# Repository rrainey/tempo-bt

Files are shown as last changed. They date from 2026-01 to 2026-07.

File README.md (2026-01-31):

# Tempo-BT

Tempo-BT is the Bluetooth-LE-capable version of the Tempo skydiving logger device.  It is based on the u-blox NORA-B106 (Nordic Semiconductor nRF5340).

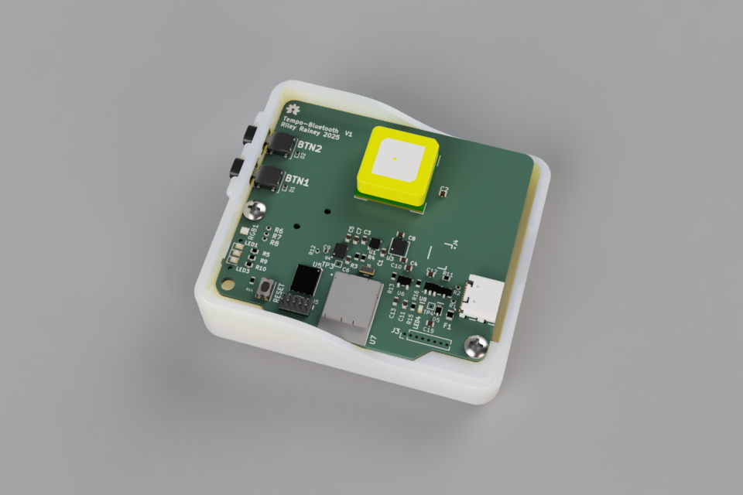
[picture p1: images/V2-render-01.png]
Tempo-BT


### Sensors and Capabilities

- GPS/GNSS position tracking using a u-blox SAM-M10Q
- 6-DOF Inertial measurement / gyro pose tracking using a TDK InvenSense ICM-42688-V
- Barometric pressure / temperature logging using a Bosch BPM390
- 3-DOF Compass/Magnetic measurement using a Memsic MMC5983MA (not utilized in the current version of the project)

## Directory Structure

| Folder | Description |
| --- | --- |
| hardware | KiCad PCB project (using KiCad 9) |
| enclosure | 3D-printable enclosure and assembly instructions (Fusion360 format) |
| zephyr/tempo-bt-v1 | Nordic nRF Connect SDK (Zephyr) firmware |

## LiPo Powered
The device is designed to use a 3.7V 850mAh rated USB-rechargeable battery.  Testing demonstrates the device and current firmware combination consumes 14.8 milliamps in idle mode and 17.4 milliamps in jump logging mode. Although I'd suggest power-cycling the device between jumps, this design should easily allow for two days of continuous use.

## Enclosure

The enclosure is designed to be SLA printable. 

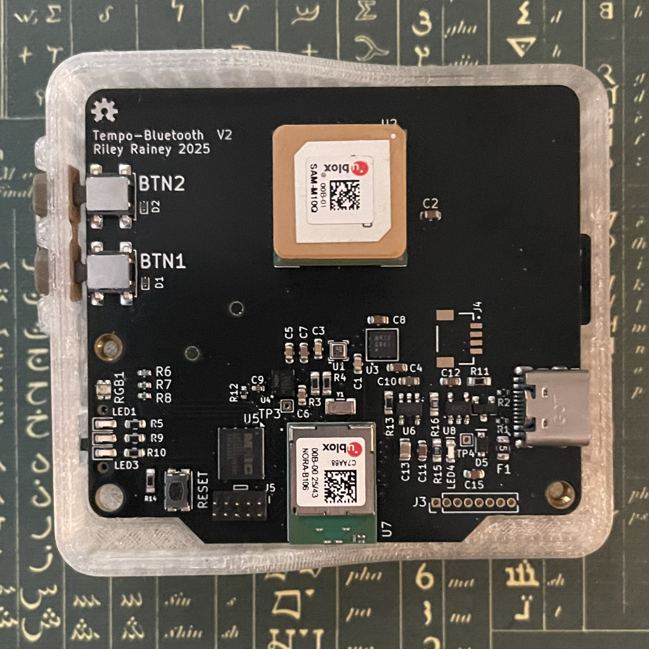
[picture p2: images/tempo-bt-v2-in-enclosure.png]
Enclosure


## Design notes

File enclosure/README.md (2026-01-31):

This snap-to-close enclosure was designed using Fusion 360 and optimized for printing using PLA filament on a Creality Ender V3 KE printer.

## Print Settings

I used the default settings in Creality Print for PLA-CR printing with a 0.4mm head and 0.2mm resolution. These settings were used for all three parts.

For other printers, here's what that amounts to:

| Parameter | Description |
|---|---|
| Filament Type | Standard PLA |
| Print Resolution | 0.2 mm |
| Brim | None |
| Supports | None - enable if Pushbutton insert doesn't fit well |
| Infill | Slicer Default (15%?) |

## Assembly

Two M2.5 brass inserts must be installed in the bottom half of the enclosure. M2.5 x 6 screws secure the PCB to the bottom enclosure.

| Quantity | Part Name | MFR Part Number | 
|---|---|---|
| 1 | Tempo BT V2 Board | NA |
| 1 | 3.7V 850mAh LiPo Battery | [13854](https://www.digikey.com/en/products/detail/sparkfun-electronics/13854/6605201) |
| 2 | Heat-Set Insert: M2.5-0.45 Thread Size | [1GNL7](https://www.grainger.com/product/Heat-Set-Insert-M2-5-0-45-1GNL7?searchQuery=1GNL7&searchBar=true) |
| 2 | Machine screw: M2.5x0.45 Thread Size, 5 mm | [1-mpp-2.5-5](https://www.grainger.com/product/Machine-Screw-M2-5x0-45-Thread-856Z30) |
| 1 | Enclosure Shell Bottom, PLA | Enclosure-Bottom.step |
| 1 | Enclosure Shell, Top, PLA | Enclosure-Top.step |
| 1 | Pushbutton Insert, PLA | Pushbutton.step |

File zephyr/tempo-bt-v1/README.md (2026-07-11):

# Tempo-BT - A Skydiving Data Logger

A Zephyr RTOS-based flight data logging system for the nRF5340 platform, designed for capturing high-frequency sensor data during skydiving and other aerial activities. The system logs IMU, barometric, GPS, and optional magnetometer data to SD card or internal flash storage, with Bluetooth LE connectivity for wireless data transfer and configuration.

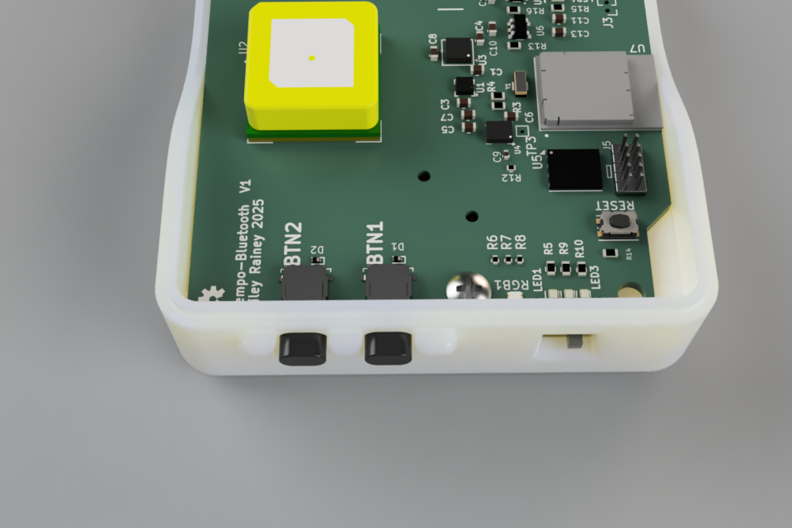
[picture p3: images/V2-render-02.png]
Tempo-BT-V2


## Table of Contents

- [Features](#features)
- [Hardware Requirements](#hardware-requirements)
- [Software Prerequisites](#software-prerequisites)
- [Build Instructions](#build-instructions)
- [Configuration](#configuration)
- [Usage Examples](#usage-examples)
- [Data Format](#data-format)
- [LED Status Indicators](#led-status-indicators)
- [Troubleshooting](#troubleshooting)
- [License](#license)
- [Support](#support)

## Features

- **Runs on the [Tempo-BT V1 Board](../../hardware/tempo-bt)**
  - open source hardware design
  - part of this GitHub repository
  - Design based on an FCC-certified u-blox NORA-B106 SOC

- **High-frequency sensor logging**
  - 50 Hz IMU data (TDK InvenSense ICM-42688-V)
  - 4 Hz barometric pressure/temperature (Bosch BMP390)
  - 2-10 Hz GPS (u-blox SAM-M10Q)
  - Optional magnetometer support (MMC5983MA) (not yet supported in firmware)

- **Flexible storage options**
  - Primary: SD card via SPI (includes exFAT support)
  - Fallback: Internal QSPI flash (littlefs)
  - Automatic storage detection at boot

- **Wireless connectivity**
  - Bluetooth LE with mcumgr protocol
  - File transfer over BLE (100-200 KB/s) (estimated)
  - Remote configuration and control
  - OTA firmware updates over BLE/SMP (MCUboot; validated 1.4.0 → 1.5.0 — see [DFU/OTA test plan](docs/dfu-ota-test-plan.md))

- **Intelligent logging**
  - Automatic logging based on environmental conditions - the device starts logging when the jumppland leaves the ground and closes the log after landing
  - State machine with flight phase detection

## Hardware Requirements

- **Development Board**: nRF5340 DK or custom Tempo-BT V2 board
- **Sensors** (connected as per hardware documentation):
  - ICM-42688-V IMU (SPI)
  - BMP390 Barometer (I²C)
  - SAM-M10Q GNSS module (115200 bps UART)
  - Optional: MMC5983MA Magnetometer (I²C)
- **Storage**: SD card (recommended) or internal 8MB QSPI flash

## Software Prerequisites

### Development Environment

1. **Visual Studio Code**
   - Download and install from [https://code.visualstudio.com/](https://code.visualstudio.com/)

2. **nRF Connect SDK v3.1.0**
   - Install the nRF Connect for VS Code extension
   - Use the extension to install nRF Connect SDK v3.1.0
   - Ensure toolchain v3.1.0 or later is selected

3. **Additional Tools**
   - Python 3.8 or higher
   - Git
   - Python `smpmgr` tool  ([link](https://pypi.org/project/smpmgr/)) (see below)

### VS Code Configuration

Configure your build in VS Code using these settings:

VS Code Build Configuration

Key configuration points:
- **SDK**: nRF Connect SDK v3.1.0
- **Toolchain**: nRF Connect SDK Toolchain v3.1.0
- **Board target**: nrf5340dk/nrf5340/cpuapp
- **Base configuration**: prj.conf
- **Device tree overlay**: boards/tempo_v1.overlay

## Build Instructions

### 1. Clone the Repository

```bash
git clone https://github.com/rrainey/tempo-bt
```

### 2. Open in VS Code

```bash
code .
```

### 3. Build the Project

Using VS Code:
1. Open the nRF Connect extension sidebar
2. Click "Add Build Configuration"
3. Select the settings as shown in the configuration image above
4. Click "Generate and Build"

Using Command Line:
```bash
west build -b nrf5340dk_nrf5340_cpuapp -p auto
```

### 4. Flash the Firmware

Using VS Code:
- Click the "Flash" button in the nRF Connect extension

Using Command Line:
```bash
west flash
```
## Interacting with the device

The device is intended for use with the [tempo-insights](https://github.com/rrainey/tempo-testbed) application suite.  It leverages the Bluetooth hardware to communicate with a Tempo-BT device.

That application repository includes extensions to the Python-based `smpmgr` command line tool ([link](https://pypi.org/project/smpmgr/)).  You can see examples of and experiment with interacting with a Tempo-BT device using that tool.

#### Notes on UUIDs

- Both `user_uuid` and `device_uuid` are automatically generated on first boot
- UUIDs are version 4 (random) format
- The `user_uuid` is intended to identify the person using the device (although we don't use that today)
- The `device_uuid` uniquely identifies this specific hardware unit
- UUIDs are displayed in standard format (e.g., `550e8400-e29b-41d4-a716-446655440000`)
- When setting UUIDs via mcumgr, provide them as 32 hex characters without dashes

#### Persistence

All settings are stored in non-volatile memory and persist across power cycles and firmware updates.

This revised section provides comprehensive documentation for all available settings, including examples of how to read and write each one using mcumgr commands.

### Manual Control

The device can also be controlled via the onboard BTN1 button (nearest the USB port):
- **BTN1 Long press (2s)**: Manually start logging

## Data Format

Jump logs are stored in a date-organized tree in `/logs/` on the device SD card.  The log file format is described in [LOG-FORMAT.md](docs/LOG-FORMAT.md)

## LED Status Indicators

A GREEN LED is used as a power indication.

The RGB LED provides visual system status:

| Color | Pattern | State |
|---|---|---|
| Off | N/A | ARMED - Ready (green / red side LEDs indicate GNSS Fix State) |
| Green | Slow pulse | Logging - waiting for aircraft exit |
| Orange | Slow pulse | Logging - in freefall or under canopy |
| White | Solid | File transfer active (not yet implemented) |
| Red | Slow pulse | Fatal Error |
| Blue | Slow Pulse | IDLE - not used in the current implementation |

Additionally, there is a dedicated RED LED which will blink when there is no usable GPS signal; the GREEN LED nearest the user buttons will flash once per second when the GNSS receiver has a valid 3D Fix.

A separate AMBER LED is the USB charging indicator.

## Firmware Update over BLE (OTA DFU)

The device supports over-the-air firmware upgrades over Bluetooth using MCUboot and the
mcumgr/SMP protocol. There is **no serial/USB DFU** — updates arrive over the same BLE link
used for file transfer. This procedure is validated (see
[DFU/OTA test plan](docs/dfu-ota-test-plan.md)); the steps below are the reusable recipe.

### How it works

The nRF5340 is dual-core, so a full update ships **two images** — the application core and
the network (radio) core — packaged together in `build/dfu_application.zip`
(`tempo-bt-v1.signed.bin` = app, `ipc_radio.bin` = net core, plus a manifest). Both images
are uploaded to staging slots in the **external QSPI flash**, marked pending, and applied on
a single reboot: MCUboot overwrites the application slot and uses the PCD library to
reprogram the network core. Images are signed and validated by MCUboot before they are
accepted.

> ⚠️ **The build is overwrite-only: there is no automatic rollback.** A bad image — most
> dangerously a bad network-core image that breaks BLE — cannot self-recover. Recovery is a
> wired SWD/J-Link re-flash of `build/merged.hex` + `build/merged_CPUNET.hex` (see
> [Flash the Firmware](#4-flash-the-firmware)). For first-time or risky updates, use a
> device you can reach with a debugger.
>
> Production flight logs are **not** touched: the DFU staging slots live in a separate region
> of the external flash from the LittleFS log partition.

### Prerequisites

- `smpmgr` on PATH (`pip install smpmgr`). The DFU path uses only smpmgr's **native**
  `image`/`os`/`file` groups — the Tempo group-64 plugin is **not** required.
- A current DFU package at `build/dfu_application.zip` (produced by the normal sysbuild build).
- The target device powered on and advertising within BLE range.

### Scripted upgrade (recommended)

[`tools/dfu-upgrade.sh`](tools/dfu-upgrade.sh) performs the whole flow for one device and
verifies it — resolve by name, stage both images, mark both pending, reset (retrying until
the swap actually applies), re-discover by name, and confirm the running image. It is
version-agnostic (the upgrade target is whatever the package stages) and touches no flight
logs.

```bash
# uses build/dfu_application.zip by default; pass a path to use a different package
tools/dfu-upgrade.sh 0006
tools/dfu-upgrade.sh 0006 /path/to/dfu_application.zip
```

It prints `RESULT Tempo-BT-0006: PASS …` and exits 0 on success. A non-zero exit before the
reset leaves the device untouched (still on the old image); a non-zero exit after means the
swap did not take — recover/inspect via SWD. Requires `smpmgr`, `bluetoothctl`, `python3`,
`unzip`; the companion state parser is [`tools/dfu_state_parse.py`](tools/dfu_state_parse.py).
The manual steps below are exactly what the script automates.

### Procedure (manual)

```bash
# 0. Extract the two images from the DFU package
cd build
unzip -o dfu_application.zip     # → tempo-bt-v1.signed.bin, ipc_radio.bin, manifest.json

# 1. Find the device address. The BLE MAC is randomly assigned at each power-on, so always
#    resolve it by advertised name (Tempo-BT-nnnn) rather than a remembered address:
bluetoothctl --timeout 8 scan on | grep "Tempo-BT-0001"     # note the AA:BB:.. address
DEV=<address-from-scan>

# 2. Baseline — confirm SMP is up and record the running image hash:
smpmgr --ble $DEV os echo hello
smpmgr --ble $DEV image state-read      # note slot0/image0 hash = the OLD firmware

# 3. Stage both images (non-destructive — the device keeps running the old firmware).
#    NOTE: smpmgr's "--slot" is really the nRF5340 IMAGE NUMBER: 0 = app core, 1 = net core.
smpmgr --timeout 30 --ble $DEV image upload tempo-bt-v1.signed.bin --slot 0
smpmgr --timeout 30 --ble $DEV image upload ipc_radio.bin          --slot 1

# 4. Confirm both are staged, and copy the two staged hashes for the next step:
smpmgr --ble $DEV image state-read
#   expect: image0/slot1 = new app hash, image1/slot1 = new net hash (both pending=False here)

# 5. Mark both staged images pending (confirm=false). THIS IS THE POINT OF NO RETURN:
smpmgr --ble $DEV image state-write <NEW_APP_HASH> false
smpmgr --ble $DEV image state-write <NEW_NET_HASH> false
smpmgr --ble $DEV image state-read      # verify both staged images now show pending=True

# 6. Apply. The device reboots, overwrites the app slot, and reprograms the net core.
#    This swap takes ~30-45 s (much longer than a plain reboot). `os reset` can silently
#    fail to trigger — if step 7 still shows the OLD hash with the images still pending,
#    the device never rebooted; re-issue os reset.
smpmgr --ble $DEV os reset

# 7. Rediscover by name (the reboot is a new power-on → the MAC may change), then verify:
bluetoothctl --timeout 8 scan on | grep "Tempo-BT-0001"     # ← must still advertise its name
DEV=<new-address-from-scan>
smpmgr --ble $DEV os echo hello                              # BLE/net core OK
smpmgr --ble $DEV image state-read                          # running slot0 hash == NEW_APP_HASH,
                                                            #   active=True, confirmed=True,
                                                            #   and the pending images are gone
```

### Acceptance checks

- `image state-read` shows the running application image hash equal to the newly-uploaded
  app image, `active` and `confirmed`. (The MCUboot image *version* field reads `0.0.0` and
  is **not** a usable version signal — verify by hash.)
- The device still advertises its assigned `Tempo-BT-nnnn` name and answers `os echo` —
  this confirms the network core survived the update.
- `smpmgr --ble $DEV file read-size <path>` responds — file transfer intact.

### Notes

- **Single-image shortcut:** for an app-core-only update you can use smpmgr's one-shot
  `smpmgr --ble $DEV upgrade <image>` (upload + mark pending + reset). The dual-core case
  above deliberately stages both images before the single reset.
- **Typical timing** (single scan adapter): app-core upload (~337 KB) ≈ 23 s, net-core
  upload (~172 KB) ≈ 13 s, and the reboot+swap (both cores) ≈ 30–45 s before the device is
  reachable again → roughly 75–90 s end to end. (A ~11 s "reboot" means the swap did **not**
  happen — the reset didn't take; re-issue it.)
- **BLE reliability:** intermittent "device not found" / dropped requests are almost always
  **BT adapter contention**, not the device — running multiple controllers at once (e.g. the
  transfer-dongle pool alongside the onboard radio) makes BlueZ/bleak discovery flaky. Do
  DFU with a single active controller if you hit this. Direct `smpmgr` connects to a known
  address are far more reliable than `bluetoothctl scan`; since a device keeps its BLE MAC
  across a reboot, verify a post-reset swap by polling its address, not by re-scanning.

## Planned firmware work

Driven by the `tempo-tb-ingest` automated-harvest workstream:

- **`SESSION_LIST` pagination** — extend the custom group-64 `SESSION_LIST` command to
  return sessions in pages, so devices holding large numbers of sessions can be
  enumerated reliably over BLE without exceeding SMP payload limits.
- **Firmware version in `settings-get`** — add a firmware-version field to the
  `settings-get` response (to be implemented alongside the pagination change). This gives
  clients a first-class version indicator; today the only over-BLE version signal is the
  MCUboot image hash (the MCUboot image *version* is `0.0.0`, so it is not usable), which
  is why the [DFU/OTA test plan](docs/dfu-ota-test-plan.md) verifies upgrades by image-hash
  match rather than a version string.

## Troubleshooting

### Common Issues

1. **SD card not detected**
   - Verify card is properly inserted
   - Validate that the SD card is readable on a PC
   - Check for supported card size (max 32GB recommended)

### Debug Output

Connect via RTT to see debug messages:
```bash
JLinkRTTViewer
```

## Acknowledgments

This project incorporates the following open-source libraries:

### Fusion AHRS Algorithm

The orientation tracking system uses the **Fusion** sensor fusion library by [xioTechnologies](https://x-io.co.uk/):

- **Project**: Fusion - Sensor Fusion Library for Inertial Measurement Units (IMUs)
- **Author**: Seb Madgwick
- **Repository**: https://github.com/xioTechnologies/Fusion
- **License**: MIT License
- **Usage**: Provides AHRS (Attitude and Heading Reference System) quaternion estimation from gyroscope and accelerometer data

The Fusion library implements a complementary filter with adaptive gain, gyroscope bias correction, and rejection of acceleration disturbances. It is specifically optimized for embedded systems.

**Citation**:
```
Madgwick, S. (2021). Fusion - Sensor Fusion Library for IMUs [Software].
Available from https://github.com/xioTechnologies/Fusion
```

## License

This project is licensed under the Apache License 2.0. See the [LICENSE](LICENSE) file for details.

```
Copyright 2025 Tempo-BT Contributors

Licensed under the Apache License, Version 2.0 (the "License");
you may not use this file except in compliance with the License.
You may obtain a copy of the License at

    http://www.apache.org/licenses/LICENSE-2.0

Unless required by applicable law or agreed to in writing, software
distributed under the License is distributed on an "AS IS" BASIS,
WITHOUT WARRANTIES OR CONDITIONS OF ANY KIND, either express or implied.
See the License for the specific language governing permissions and
limitations under the License.
```

## Support

For questions, bug reports, or feature requests:

- **Primary Contact**: Riley Rainey ([@rileyrainey](https://x.com/rileyrainey) on X.com)
- **Issues**: Please file issues on the project's GitHub repository
- **Documentation**: Additional documentation can be found in the `docs/` directory

### Contributing

Contributions are welcome!

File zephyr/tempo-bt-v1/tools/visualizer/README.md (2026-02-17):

# Tempo-BT Orientation Visualizer

This Python desktop application connects to a Tempo-BT device over USB and renders its real-time orientation in 3D. It parses the `$PIM2` (quaternion) and `$PIMU` (accelerometer/gyroscope) NMEA sentences from the Tempo-BT USB TTY log stream.

The application demonstrates the Tempo device's ability to compute a skydiver's orientation in real time using the on-board ICM-42688 IMU and Fusion AHRS algorithm. A telemetry overlay displays live accelerometer and gyroscope readings alongside the 3D view.

## Prerequisites

- Tempo-BT device with firmware v1.1.0 or later (USB CDC-ACM support)
- USB cable connecting Tempo-BT to your desktop machine
- Python 3.9+

## Setup

1. Open a terminal in the `tools/visualizer` folder.

2. Set up a Python virtual environment (recommended):

```
$ python -m venv .venv
$ .venv\Scripts\activate
```

or Powershell:

```
> .venv\\Scripts\\Activate.ps1 
```

On Windows, you may need to allow script execution first:
```
> Set-ExecutionPolicy -ExecutionPolicy RemoteSigned -Scope CurrentUser
```

3. Install dependencies:

```
> pip install -r requirements.txt
> pip install PyOpenGL PyOpenGL_accelerate
```

*Installation of `PyOpenGL_accelerate` is optional.* It may require Microsoft Visual Studio or a prebuilt wheel. See [this guide](https://stackoverflow.com/questions/77346740/install-pyopengl-for-windows-under-python-3-12) for prebuilt options.

## Running

1. Connect Tempo-BT to your desktop via USB.

2. Start the visualizer:

```
> python visualizer.py
```

The application auto-detects the Tempo-BT device by its USB VID (`0x1209`) and PID (`0x2026`). If auto-detection fails (e.g., multiple devices or driver issues), specify the port manually:

```
> python visualizer.py --port COM8
```

3. On the Tempo-BT device, long-press **BTN2** (2 seconds) to start the USB log stream.

4. The 3D model will rotate to mirror the device's physical orientation. The top-right overlay shows live IMU telemetry (accelerometer in m/s², gyroscope in rad/s).

5. Long-press **BTN2** again to stop streaming, or simply disconnect the USB cable.

## Keyboard Controls

| Key | Action |
|-----|---|
| **F** | Front view |
| **R** | Right view |
| **Q** | Quit |

## NMEA Sentences

The visualizer processes these sentences from the USB stream:

| Sentence | Rate | Usage |
|---|---|---|
| `$PIM2` | 20 Hz | Quaternion orientation (w, x, y, z) for 3D rendering |
| `$PIMU` | 20 Hz | Accelerometer + gyroscope values for telemetry overlay |

All other sentences (`$PENV`, `$PST`, `$PVER`, `$GxGGA`, `$GxVTG`, `$GxRMC`, etc.) are silently ignored.

## Troubleshooting

- **"No Tempo-BT device found"**: Ensure the device is connected via USB and appears as a COM port in Device Manager. Use `--port COMx` if auto-detection fails.
- **No data streaming**: Make sure you long-pressed Button 1 / BTN2 on the Tempo-BT to start the USB log stream. The green LED indicates the device is in LOGGING state.
- **3D model orientation seems wrong**: Set the device flat on your desk with the USB connector coming out the left side, then press F for front view to establish a reference.

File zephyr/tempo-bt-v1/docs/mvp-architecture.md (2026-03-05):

# Tempo-BT (V1) — Zephyr Device Application Architecture

> Scope: architecture for the **V1 prototype** (nRF5340 / NORA-B106) with ICM-42688-V (SPI), BMP390 (I²C), optional MMC5983MA (I²C), u-blox SAM-M10Q (UART), **SD Card** (FAT/exFAT).
> Focus areas per request:
>
> 1. **File + folder (project) structure**
> 2. **What each part does**
> 3. **Where state lives & how services connect**

---

## 1) Project Layout (top-level folders and key files)

```
tempo-bt/
├─ CMakeLists.txt                # Zephyr app build entry
├─ prj.conf                      # Kconfig: features, stacks, logging, BLE, FS
├─ Kconfig                       # App-specific config symbols (USB_TTY_OUTPUT, etc.)
├─ west.yml                      # (optional) NCS/Zephyr manifest pinning
│
├─ boards/
│  └─ nrf5340dk_nrf5340/
│     ├─ tempo_v1.overlay        # DeviceTree overlay: pins/buses/IRQs/USB for V1
│     └─ tempo_v1.conf           # Board-specific prj.conf deltas (if needed)
│
├─ include/
│  ├─ app/events.h               # Event IDs, payloads, and helper macros
│  ├─ app/log_format.h           # $Pxxx sentence format & helpers (NMEA)
│  │
│  ├─ services/timebase.h        # Time service API (monotonic, GNSS tie)
│  ├─ services/imu.h             # ICM42688 sample structs & API
│  ├─ services/baro.h            # BMP390 sample structs & API
│  ├─ services/gnss.h            # GNSS NMEA/UBX ingest API
│  ├─ services/aggregator.h      # Merges streams → record/sentence builder
│  ├─ services/logger.h          # Logging session lifecycle & policies
│  ├─ services/file_writer.h     # Async buffered writer (ring buffer)
│  ├─ services/storage.h         # Storage abstraction (littlefs/FATFS)
│  ├─ services/orientation.h     # AHRS/orientation tracking API
│  ├─ services/led.h             # RGB LED service API
│  ├─ services/usb_tty.h         # USB CDC-ACM TTY output API (ground test)
│  │
│  └─ fusion.h                   # Fusion AHRS algorithm headers
│
├─ src/
│  ├─ main.c                     # Init order, button handling, event loop
│  ├─ app_init.c                 # Storage mount, BLE/mcumgr initialization
│  ├─ events.c                   # Event bus (k_fifo/k_msgq) + subscribers
│  ├─ fusion.c                   # Fusion AHRS algorithm (xioTechnologies)
│  │
│  ├─ services/
│  │  ├─ timebase.c             # 64-bit mono clock; GNSS time correlation
│  │  ├─ imu_icm42688.c         # SPI4 + INT1/FIFO DMA; ODR control
│  │  ├─ baro_bmp390.c          # I²C + DRDY; pressure/temperature
│  │  ├─ gnss_m10q.c            # UART async; NMEA/UBX parse; early quiet
│  │  ├─ aggregator.c           # Streams → `$PIMU/$PIM2/$PENV/...` w/ checksums
│  │  ├─ orientation.c          # AHRS wrapper using Fusion algorithm
│  │  ├─ logger.c               # Session mgmt; start/stop; takeoff detection
│  │  ├─ file_writer.c          # Ring buffer + worker thread
│  │  ├─ storage.c              # Storage abstraction layer
│  │  ├─ storage_littlefs.c     # QSPI NOR backend (optional)
│  │  ├─ storage_fatfs.c        # SD Card FAT/exFAT backend (primary)
│  │  ├─ usb_tty.c              # USB CDC-ACM TTY output (conditional)
│  │  └─ led.c                  # PWM-based RGB LED control
│  │
│  └─ util/
│     └─ nmea_checksum.c        # NMEA checksum utilities
│
├─ config/
│  └─ settings.c                 # Zephyr settings keys & defaults (`app/*`)
│
├─ docs/
│  └─ mvp-architecture.md        # This document
│
├─ tools/
│  └─ patch_rmc.py               # Retroactively insert RMC into old log files
│
└─ scripts/
   └─ host_tools/verify_log.py   # PC-side log validator
```

---

## 2) Runtime Architecture (what each part does)

### 2.1 Layered view

**Current implementation status:**
- ✓ BMP390 barometer (working, 8Hz with takeoff detection)
- ✓ GNSS SAM-M10Q (working, 1-10Hz dynamic, UBX config, RMC passthrough)
- ✓ SD Card storage (FAT/exFAT, primary storage)
- ✓ Orientation tracking (Fusion AHRS algorithm)
- ✓ RGB LED status (PWM-based, state indication)
- ✓ Button controls (short/long press handling)
- ✓ BLE file transfer (mcumgr)
- ✓ ICM42688 IMU (200Hz FIFO, filtered accel magnitude for freefall detection)
- ✓ Flight phase detection (takeoff, freefall, landing)
- ✓ USB CDC-ACM TTY output (ground testing via Button 1 / BTN2)
- ✓ MMC5983MA magnetometer (calibration via USB, AHRS integration, NVM persistence)

```mermaid
flowchart TB
  subgraph App["Application Layer"]
    Main[main.c\nButton handlers\nExecutive loop 250ms]
    Logger[Logger Service\nState machine\nFlight phase detection]
    LED[LED Service\nPWM RGB status]
  end

  subgraph Services["Core Services"]
    Agg[Aggregator\nSentence builder\nRing buffers]
    Orient[Orientation\nFusion AHRS]
    Writer[File Writer\nRing buffer + thread]
    UsbTty[USB TTY\nCDC-ACM output\nGround test mode]
    Tm[Timebase\n64-bit mono + RTC]
  end

  subgraph Drivers["Sensor + IO Drivers"]
    IMU[ICM42688 SPI\n200Hz FIFO\nFiltered accel mag]
    BARO[BMP390 I²C\nAlpha-beta filter]
    GNSS[SAM-M10Q UART\n1-10Hz dynamic]
    Storage[SD Card FAT]
  end

  Main --> Logger
  Main --> LED
  Logger --> Agg
  IMU --> Orient
  IMU --> Logger
  BARO --> Agg
  BARO --> Logger
  GNSS --> Agg
  Tm --> Agg
  Orient --> Agg

  Agg --> Writer --> Storage
  Agg -.-> UsbTty -.-> USB[USB Host]
```

### 2.2 Concurrency model (threads & priorities)

| Thread | Priority | Purpose |
|---|---|---|
| **File writer** | `K_PRIO_PREEMPT(10)` | Drains ring buffer to SD card |
| **Aggregator** | `K_PRIO_PREEMPT(5)` | Builds NMEA sentences |
| **GNSS RX** | `K_PRIO_PREEMPT(5)` | UART async callback context |
| **Main** | Default | Button handling, health monitoring |

**Communication primitives:**

* **Ring buffer** (Zephyr `sys/ring_buffer.h`) in file_writer for async I/O
* **Ring buffer** in USB TTY for interrupt-driven CDC-ACM TX (4KB)
* **Spinlock-protected ring buffers** in aggregator for IMU/BARO/GNSS samples
* **Event bus** (`k_fifo`/`k_msgq`) for state change notifications
* **Mutexes** for thread-safe stats access and orientation state
* **Work items** (`k_work`, `k_work_delayable`) for deferred ISR-to-thread actions (buttons, USB disconnect)

---

## 3) Where State Lives

### 3.1 Persistent configuration (NVS / `settings`)

* Stored via Zephyr `settings` in internal flash
* Loader in `config/settings.c`
* Keys include BLE name, rate settings

### 3.2 System state (RAM, owned by logger service)

* **Logger state** (`logger_state_t`) serves as the primary system state:
  * States: `IDLE` → `ARMED` → `LOGGING` → `JUMPED` → `POSTFLIGHT` → `ERROR`
  * Manages session lifecycle and health metrics
  * Thread-safe access via mutex

* **Test alarm state** (in `mcumgr_custom.c`):
  * States: `TEST_ALARM_IDLE`, `TEST_ALARM_WAITING_START`, `TEST_ALARM_WAITING_JUMP`
  * Target UTC time and jump delay parameters
  * Processed by `timebase.c` on each PPS pulse

* **Sensor caches** (in respective services):
  * **BARO**: last pressure/temp, altitude estimate, ground reference
  * **GNSS**: last fix (position, velocity, time), RTC correlation
  * **Orientation**: current quaternion (Fusion AHRS state)

* **Session state** (in logger, lifetime = active logging session):
  * `session_start_us` (monotonic timestamp)
  * `session_dir` (path to session directory)
  * File writer statistics (bytes, lines, flushes)

### 3.3 Filesystem state

* **Primary**: SD Card with FAT/exFAT filesystem
* **Fallback**: QSPI NOR with littlefs (optional)
* **Path scheme**: `/SD:/logs/<YYYYMMDD>/<UUID>.txt`
* **Date folders**: Created using GPS date when available

---

## 4) Services — Responsibilities & Interfaces

### 4.1 `timebase`

* Provides `time_now_us()` (64-bit monotonic)
* Maintains GNSS time correlation: updated by GNSS sentences
* Sets system RTC (`CLOCK_REALTIME`) from GPS time for date-stamped directories
* **PPS (Pulse Per Second)**: Handles GNSS 1Hz time pulse interrupt for precise timing
* **ISO 8601 datetime**: `timebase_get_utc_iso8601()` returns current UTC as `YYYY-MM-DDTHH:MM:SS.dZ`
* **Test alarm processing**: PPS-triggered work handler for synchronized multi-device testing

### 4.2 `imu_icm42688`

* Configures ODR (200 Hz), full-scale ranges; enables FIFO streaming
* SPI bursts to read FIFO; polled by orientation service at 20 Hz
* **Filtered acceleration magnitude API** for freefall detection:
  * `imu_enable_accel_filter()` / `imu_disable_accel_filter()` - enable/disable filtering
  * `imu_get_filtered_acceleration()` - get EMA-filtered magnitude in g
  * EMA filter with α=0.15 (~33ms time constant at 200Hz)
  * Enabled automatically when entering LOGGING state

### 4.3 `baro_bmp390`

* Configures ODR (default 8 Hz); fires on DRDY IRQ
* Outputs pressure, temperature, and calculated altitude
* Provides ground altitude reference for takeoff detection
* Callback registration for logger (takeoff detection) and aggregator (logging)

### 4.4 `gnss_m10q`

* **UART async API** with ring buffer for received data
* **Early quiet**: `gnss_early_quiet()` called at boot to silence module before full init
* **NMEA parsing**: GGA, VTG, RMC sentences passed through to log
* **UBX protocol**: Configuration commands (rate, dynamic model, message enable/disable)
* **UBX retry**: `ubx_send_with_retry()` wrapper retries failed CFG-MSG commands (occasional ACK failures)
* **Dynamic model**: Airborne 4g for skydiving operations
* **Rate control**: 1 Hz default, configurable up to 10 Hz; GSA and RMC disabled at rates > 1 Hz to reduce NMEA bandwidth, re-enabled at 1 Hz

### 4.5 `orientation` + `fusion`

* **Fusion AHRS algorithm** (based on xioTechnologies/Fusion library)
* IMU + magnetometer operation when `mag_mode > 0` and calibration is valid
* Falls back to IMU-only (gyro + accel) when magnetometer is disabled or unavailable
* Outputs quaternion orientation updated from IMU samples
* Magnetometer data supplied via `mag_read_fusion()` with coordinate frame rotation to match IMU axes
* Configurable gain and acceleration rejection thresholds

### 4.6 `aggregator`

* **Ring buffers** for IMU (128 samples), BARO (32 samples), GNSS (32 fixes)
* **NMEA sentence builder** with checksum calculation
* **Output sentences**:
  * `$PVER` - Version info at session start
  * `$PSFC` - Surface/ground altitude
  * `$PIMU` - IMU data (20 Hz when IMU working)
  * `$PIM2` - Quaternion orientation (after each `$PIMU`)
  * `$PENV` - Environmental data (4 Hz) - pressure, altitude, battery
  * `$PTH` - Timestamp correlation (after GGA/GLL)
  * `$PST` - State change events
  * Raw GNSS: `$GxGGA`, `$GxVTG`, `$GxRMC` passthrough
* **Work-based output**: Delayable work items for timed sentence emission

### 4.7 `logger`

* **Session state machine**: IDLE → ARMED → LOGGING → JUMPED → POSTFLIGHT → ERROR
* **Executive function** (runs every 250ms):
  * Manages automatic state transitions based on flight phase detection
  * Uses alpha-beta filter for climb rate estimation from barometric data
  * Median pre-filter (3 samples) for altitude outlier rejection
* **Takeoff detection** (ARMED → LOGGING):
  * Threshold: Climb rate > 200 ft/min (1.016 m/s)
  * Confirmation: 3 consecutive seconds
* **Freefall detection** (LOGGING → JUMPED) - dual methods:
  * **Barometric**: Descent rate < -1000 ft/min for 2 seconds
  * **Accelerometer**: Magnitude < 0.6g for 500ms (2 readings at 250ms) - *faster response*
* **Landing detection** (JUMPED → ARMED):
  * Threshold: |climb rate| < 200 ft/min
  * Confirmation: 60 seconds of low activity
* **Abort timeout** (LOGGING → ARMED):
  * If no jump detected after 6 minutes of low activity, returns to ARMED
* **Session management**:
  * Creates date-based directories using GPS date
  * UUID-based filenames
  * Writes header (PVER, PSFC) at session start
* **USB ground test mode** (`logger_start_usb()`):
  * Streams identical NMEA data over USB CDC-ACM instead of SD card
  * Triggered by Button 1 / BTN2 long press when USB host is connected
  * Registers `usb_tty_output_line` as aggregator output callback
  * Registers disconnect callback to auto-stop on USB cable removal
  * Sets `usb_mode` flag — suppresses executive auto-transitions (no flight phase detection)
  * `logger_stop()` calls `usb_tty_close()` instead of file_writer cleanup when in USB mode
* **Button control integration**: Armed/disarmed via Button 0 / BTN1 long press, start/stop via short press; USB logging via Button 1 / BTN2 long press

### 4.8 `file_writer`

* **Simplified architecture**: Ring buffer + dedicated worker thread
* **Static allocations**: 8KB ring buffer, 4KB write buffer, 1KB thread stack
* **Async operation**: Data queued via `file_writer_write()`, flushed by worker
* **Periodic flush**: Default 250ms interval
* **Statistics**: Bytes written, lines, flushes, buffer overflows, write errors

### 4.9 Storage Backends

* **Primary**: `storage_fatfs.c` - SD Card with FAT/exFAT
  * Mount point: `/SD:`
  * Auto-creates directory paths
  * Card detect GPIO support
* **Optional**: `storage_littlefs.c` - QSPI NOR flash
* **Abstraction**: `storage.c` provides unified interface

### 4.10 `led`

* **PWM-based RGB LED** control (3 channels)
* **Blink pattern**: 50ms on, 2 second period
* **State colors**:
  * Blue: IDLE
  * Orange: ARMED
  * Green: LOGGING
  * Red: ERROR
* **Override support**: Temporary color override for status indication

### 4.11 BLE / mcumgr

* Standard mcumgr file transfer over BLE SMP
* File list/get/delete operations
* Dynamic device name support (`CONFIG_BT_DEVICE_NAME_DYNAMIC`)

**Custom Tempo Commands** (Group ID 64):

| ID | Command | Type | Description |
|----|---|---|---|
| 0 | `SESSION_LIST` | Read | List logging sessions |
| 2 | `STORAGE_INFO` | Read | Get storage backend and free space |
| 3 | `LED_CONTROL` | Write | Set RGB LED color override |
| 4 | `LOGGER_CONTROL` | Write | Start/stop/arm/disarm logger |
| 5 | `SESSION_DELETE` | Write | Delete a logging session |
| 6 | `SETTINGS_GET` | Read | Get NVM settings (BLE name, PPS, PCB variant) |
| 7 | `SETTINGS_SET` | Write | Update NVM settings |
| 8 | `GET_DATETIME` | Read | Get current UTC as ISO 8601 (`YYYY-MM-DDTHH:MM:SS.dZ`) |
| 9 | `TEST_LOGGING` | Write | Schedule synchronized logging test (see below) |

**TEST_LOGGING Command**:

Used for multi-device synchronized testing via GNSS PPS signal.

* **Request**: `{"start": "MMSS", "jump": nn}`
  * `start`: Minutes and seconds within current UTC hour to begin logging
  * `jump`: Seconds after start to transition to JUMPED state (0-3600)
* **Response**: `{success, start_mm, start_ss, seconds_until_start, jump_delay}`
* **Behavior**:
  * Requires valid GNSS time correlation (returns error if unavailable)
  * If MMSS has passed in current hour, schedules for next hour
  * Auto-arms logger if in IDLE state
  * PPS interrupt triggers `logger_start()` at exact second boundary
  * After `jump` seconds, triggers `logger_jumped()` for state transition
  * Logger executive handles session closure after landing detection

### 4.12 `usb_tty` (conditional: `CONFIG_USB_TTY_OUTPUT`)

* **USB CDC-ACM** virtual UART over the nRF5340's built-in USB peripheral
* **Bidirectional**: TX ring buffer for non-blocking output + RX line accumulation for host commands
* **Ground test mode**: streams the same NMEA sentence data that normally goes to SD card
* **Mag calibration mode**: streams `$PRMG` sentences and accepts `$PCMD` commands (see `usb_cmd`)
* **Interrupt-driven TX** with 4KB ring buffer for non-blocking writes
* **Interrupt-driven RX**: ISR accumulates bytes into 128-byte line buffer; on `\n`, copies to second buffer and submits `k_work` for workqueue dispatch
* **Connection detection**: checks DTR line control first, falls back to USB configured state (many Windows terminals don't assert DTR)
* **Disconnect detection**: polls DTR while open; also monitors USB stack status callback (`USB_DC_DISCONNECTED`/`USB_DC_SUSPEND`)
* **Disconnect notification**: fires registered callback via `k_work` (not from ISR context) so caller can safely stop
* **API**:
  * `usb_tty_init()` — enables USB device stack, called once at boot
  * `usb_tty_is_connected()` — checks if a USB host is present
  * `usb_tty_open()` / `usb_tty_close()` — session lifecycle
  * `usb_tty_output_line()` — matches `aggregator_output_callback_t` signature
  * `usb_tty_register_disconnect_callback()` — DTR-drop / USB-disconnect notification
  * `usb_tty_register_rx_callback()` — register line-received callback (dispatched from workqueue)

### 4.13 `mag_mmc5983ma` (conditional: `CONFIG_MMC5983MA`)

* **MMC5983MA magnetometer driver + service** on I2C bus
* **Single-shot reads** with automatic SET/RESET demagnetization cycle for offset cancellation
* **Calibration data** (`mag_calibration_t`):
  * Offsets: `offset_x`, `offset_y`, `offset_z` (int32_t, raw LSB units)
  * Scales: `scale_x`, `scale_y`, `scale_z` (uint16_t, Q1.15 fixed-point, 32768 = 1.0)
  * `valid` flag
* **NVS persistence**: calibration stored under `mag/cal` settings key; loaded at boot, saved via `mag_cal_save()`
* **Coordinate frame rotation**: `mag_read_fusion()` rotates raw readings to match IMU axis convention for AHRS integration
* **Calibration data management API**:
  * `mag_cal_get()` / `mag_cal_set()` — read/write in-memory calibration
  * `mag_cal_save()` / `mag_cal_load()` — NVS persistence
  * `mag_cal_clear()` — reset to uncalibrated defaults
* **`mag_read_fusion()`** — returns calibrated, axis-rotated magnetometer vector for orientation service

### 4.14 `usb_cmd` (conditional: `CONFIG_USB_TTY_OUTPUT`)

* **NMEA-style command/response protocol** over USB CDC-ACM
* **Active only during mag calibration streaming mode** — gated by `usb_cmd_set_active(bool)`
* **Command format**: `$PCMD,<verb>[,args]*HH\r\n`
* **Response format**: `$PRSP,<verb>,<result>[,data]*HH\r\n`
* **Checksum validation**: NMEA XOR checksum verified on all incoming commands
* **Commands**:

| Command | Host → Device | Device → Host |
|---|---|---|
| CAL_GET | `$PCMD,CAL_GET*HH` | `$PRSP,CAL_GET,<valid>,<ox>,<oy>,<oz>,<sx>,<sy>,<sz>*HH` |
| CAL_SET | `$PCMD,CAL_SET,<ox>,<oy>,<oz>,<sx>,<sy>,<sz>*HH` | `$PRSP,CAL_SET,OK*HH` or `$PRSP,CAL_SET,ERR,<code>*HH` |
| MODE_GET | `$PCMD,MODE_GET*HH` | `$PRSP,MODE_GET,<mode>*HH` |
| MODE_SET | `$PCMD,MODE_SET,<mode>*HH` | `$PRSP,MODE_SET,OK*HH` or `$PRSP,MODE_SET,ERR,<code>*HH` |

* **Processing context**: RX callback registered with `usb_tty`; commands dispatched from system workqueue (safe for NVS flash writes)

---

## 5) How Services Connect

### 5.1 Data plane (samples → sentences → storage)

```mermaid
sequenceDiagram
  participant BARO
  participant GNSS
  participant AGG as Aggregator
  participant Orient as Orientation
  participant WR as File Writer
  participant SD as SD Card
  participant USB as USB TTY

  BARO->>AGG: push sample (ring buffer)
  GNSS->>AGG: NMEA passthrough + fix data
  AGG->>Orient: IMU samples (when available)
  Orient->>AGG: quaternion

  AGG->>AGG: build $PENV/$PTH/GNSS sentences
  alt SD card mode (normal)
    AGG->>WR: output callback (NMEA line)
    WR->>WR: ring buffer enqueue
    WR->>SD: worker thread flush
  else USB mode (ground test)
    AGG->>USB: output callback (NMEA line)
    USB->>USB: ring buffer + IRQ TX
  end
```

### 5.2 Control plane (events & state)

* `events.c` exposes `event_bus_publish()` and subscriber registration
* **Producers**: logger, storage, sensors
* **Consumers**: LED service (state colors), aggregator (`$PST` sentences)

**Event types:**
* `EVT_MODE_CHANGE` - Logger state transitions
* `EVT_STORAGE_ERROR` - SD card errors
* `EVT_SENSOR_ERROR` - Sensor failures
* `EVT_STORAGE_LOW` - Low storage warning

---

## 6) Session Lifecycle (state machine)

```mermaid
stateDiagram-v2
    [*] --> IDLE
    IDLE --> ARMED: long-press Button 0 / BTN1
    IDLE --> LOGGING: TEST_LOGGING alarm (auto-arms)
    IDLE --> LOGGING: long-press Button 1 / BTN2 (USB mode)
    ARMED --> IDLE: long-press Button 0 / BTN1
    ARMED --> LOGGING: short-press or takeoff detected (3s climb)
    ARMED --> LOGGING: TEST_LOGGING alarm
    ARMED --> LOGGING: long-press Button 1 / BTN2 (USB mode)
    LOGGING --> JUMPED: freefall detected (baro 2s or accel 500ms)
    LOGGING --> JUMPED: TEST_LOGGING jump timer
    LOGGING --> ARMED: 6 min low activity (abort)
    LOGGING --> IDLE: short-press Button 0 / BTN1 (manual stop)
    LOGGING --> IDLE: long-press Button 1 / BTN2 (stop USB)
    LOGGING --> IDLE: USB host disconnect (USB mode only)
    LOGGING --> ERROR: storage/sensor error
    JUMPED --> ARMED: landing detected (60s low activity)
    JUMPED --> IDLE: short-press (manual stop)
    ERROR --> IDLE: recovery
```

**Button Controls (main.c):**

> Note: Zephyr code uses 0-indexed names (`button0`, `button1`) while PCB silkscreen uses 1-indexed labels (`BTN1`, `BTN2`).

- **Button 0 / BTN1 long press** (2 seconds): Toggle IDLE ↔ ARMED
- **Button 0 / BTN1 short press**: Start logging (when ARMED) or stop logging (when LOGGING/JUMPED)
- **Button 1 / BTN2 short press**: Toggle magnetometer calibration streaming mode (requires USB host); streams `$PRMG` at 20 Hz and accepts `$PCMD` commands
- **Button 1 / BTN2 long press** (2 seconds): Start USB TTY logging (when IDLE or ARMED, requires USB host); stop logging (when LOGGING/JUMPED, works for both USB and SD modes)

**Automatic Flight Phase Detection (executive function @ 250ms):**

| Transition | Method | Threshold | Confirmation |
|---|---|---|---|
| ARMED → LOGGING | Barometric climb | > 200 ft/min | 3 seconds |
| LOGGING → JUMPED | Barometric descent | < -1000 ft/min | 2 seconds |
| LOGGING → JUMPED | Accelerometer low-g | < 0.6g | 500ms (faster) |
| LOGGING → ARMED | Low activity abort | \|rate\| < 200 ft/min | 6 minutes |
| JUMPED → ARMED | Landing detection | \|rate\| < 200 ft/min | 60 seconds |

**Test Alarm Synchronization (mcumgr TEST_LOGGING):**
- Schedules LOGGING start at specific UTC wall clock time (MMSS within hour)
- Uses GNSS PPS signal for precise 1-second boundary triggering
- Enables simultaneous logging start across multiple Tempo-BT devices
- Optional jump delay triggers LOGGING → JUMPED transition after N seconds

Transitions emit `$PST` records with trigger reasons.

---

## 7) Logging Format

Uses **NMEA-style** `$Pxxx` proprietary sentences with checksums.

### Sentence Types

| Sentence | Rate | Description |
|---|---|---|
| `$PVER` | Once | Version info: `"Tempo V1 <version> (<git>)",<numeric>` |
| `$PSFC` | Once | Surface/ground altitude in feet |
| `$PIMU` | 20 Hz | Accel (m/s²) + gyro (rad/s) - when IMU working |
| `$PIM2` | 20 Hz | Quaternion (w,x,y,z) - after each PIMU |
| `$PENV` | 4 Hz | Pressure (hPa), altitude (ft), battery (V) |
| `$PTH` | Per fix | Timestamp correlation (ms since session start) |
| `$PST` | Events | State change: old_state, new_state, trigger |
| `$GxGGA` | 1 Hz or 10 Hz| GNSS fix (passthrough) |
| `$GxVTG` | 1 Hz or 10 Hz| GNSS velocity (passthrough) |
| `$GxRMC` | 1 Hz or 10 Hz| GNSS date/time/position/velocity (passthrough, 1 Hz mode only) |
| `$PMAG` | 20 Hz | Calibrated magnetometer (x,y,z in µT) - when mag enabled and logging |
| `$PRMG` | 20 Hz | Raw magnetometer (x,y,z LSB) - USB calibration streaming only |
| `$PCMD` | Host→Device | USB command (CAL_GET, CAL_SET, MODE_GET, MODE_SET) |
| `$PRSP` | Device→Host | USB command response |

### Checksum Format

All sentences end with `*HH\r\n` where HH is XOR checksum of characters between `$` and `*`.

---

## 8) Error Handling

* **Ring buffer overflow**: Tracked in file_writer stats; logged as warning
* **Storage errors**: Trigger `EVT_STORAGE_ERROR`; logger transitions to ERROR state
* **Sync policy**: Writer syncs after each flush; final sync on file close
* **GNSS buffer overrun**: Mitigated by `gnss_early_quiet()` at boot

---

## 9) Implementation Status

### Working
- ✓ SD Card storage (FAT/exFAT)
- ✓ BLE file transfer (mcumgr)
- ✓ BMP390 barometer (8 Hz, takeoff detection)
- ✓ SAM-M10Q GNSS (1-10 Hz, UBX config, airborne 4g mode, RMC passthrough)
- ✓ ICM42688 IMU (200 Hz FIFO, orientation tracking, filtered accel magnitude)
- ✓ Orientation tracking (Fusion AHRS with IMU data)
- ✓ Logger state machine (IDLE/ARMED/LOGGING/JUMPED/ERROR)
- ✓ Button controls (Button 0 / BTN1 short/long press; Button 1 / BTN2 long press for USB)
- ✓ RGB LED status indication
- ✓ Event bus for state notifications
- ✓ Date-stamped log directories (GPS date)
- ✓ Async file writer (ring buffer + worker thread)
- ✓ Custom mcumgr commands (session/storage/LED/logger/settings control)
- ✓ PPS-synchronized test logging (multi-device synchronization)
- ✓ UTC datetime query (ISO 8601 format)
- ✓ **USB CDC-ACM TTY output** (ground test mode via Button 1 / BTN2):
  - Streams NMEA data over USB serial instead of SD card
  - Auto-stop on USB host disconnect or Button 1 / BTN2 long press
  - Executive auto-transitions suppressed in USB mode
- ✓ **Flight phase detection** (executive function @ 250ms):
  - Takeoff detection (barometric climb rate)
  - Freefall detection (dual: barometric descent + accelerometer low-g)
  - Landing detection (sustained low vertical activity)
  - Session abort (6 min timeout in LOGGING without jump)

- ✓ **MMC5983MA magnetometer**:
  - Single-shot reads with SET/RESET demagnetization
  - Calibration via USB streaming (`$PRMG`) + Python tool (`mag_cal.py`)
  - NVS persistence of calibration data (`mag/cal` settings key)
  - USB command protocol (`$PCMD`/`$PRSP`) for cal upload and mag_mode control
  - AHRS integration via `mag_read_fusion()` (coordinate-frame rotated)
  - `mag_mode` setting: 0=disabled, 1=factory cal, 2=NVM cal

### Not Working / Pending
- (none currently)

---

## 10) Key Configuration (prj.conf)

```conf
# Heap for dynamic allocations
CONFIG_HEAP_MEM_POOL_SIZE=16384

# BLE with dynamic device name
CONFIG_BT_DEVICE_NAME_DYNAMIC=y
CONFIG_BT_DEVICE_NAME_MAX=32

# Filesystem
CONFIG_FILE_SYSTEM=y
CONFIG_FAT_FILESYSTEM_ELM=y
CONFIG_DISK_ACCESS=y

# UART: async for GNSS, interrupt-driven for CDC-ACM
CONFIG_UART_ASYNC_API=y
CONFIG_UART_INTERRUPT_DRIVEN=y
# Per-instance override: keep hardware UARTs on async API
CONFIG_UART_0_INTERRUPT_DRIVEN=n
CONFIG_UART_2_INTERRUPT_DRIVEN=n

# USB CDC-ACM for ground test output
CONFIG_USB_DEVICE_STACK=y
CONFIG_USB_CDC_ACM=y
CONFIG_USB_DEVICE_VID=0x1209
CONFIG_USB_DEVICE_PID=0x2026
CONFIG_USB_DEVICE_PRODUCT="Tempo-BT"
```

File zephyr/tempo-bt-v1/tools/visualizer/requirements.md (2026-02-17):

# Tempo Insights Application

**Tempo Insights** will be a web-based application designed to securely collect and analyze jump logs collected by Tempo-BT jump logging devices. The application will be designed to run on Raspberry Pi 5 servers. It will include a Bluetooth-capable component designed to interact at the local drop zone with logging devices with ontly a minimal requirement for user interactions with the devices.  Under normal operating circumstances, the User/Jumper simply turns the device on, makes a jump, and the Tempo Insights application will automatically discover, upload, and securely store information about the jump.  The Jumper/User can then log into the application via the web and review their results.

## Core Application Objects

**Users** A user provides an e-mail address, their Full Name, and a password, which is stored as a secure hash. Users may be granted an "Administrator" role. The system will be initially provisioned with an "Administrator" user. That user will automatically be granted the Administrator role.  Some application activities will only be available to Administrators - these will be described later.
**Jump Log** A user will accumulate jump logs in the application via one or more Devices assigned to them.  The Jump Log record will consist of the integer Jump Number (which will be assigned automatically), the date/time of the jump (local time zone; this will be an estimated timestamp of the exit from the aircraft, estimated by reviewing the log contents - more details on the data model requirements later), a blob containing the actual jump data file received from the logging device, a SHA-256 hash code of the log file contents, and user editable notes about the jump. A jump log record is always visible to the owning user.  A "Visible to Connections" flag is also associated with the record.  By default, this will be True when the log record is first gathered.  A user can make the record hidden from others, by clearing this "Visible to Connections" flag. A user will have zero or more associated Jump Logs.
**Groups** Groups are collections of Users. A User may be a member of zero or more Groups. A User may be an Administrator or a Member of a Group.  A User may create a Group on demand from the UI.  They specify a name and description.  This User automatically become a member of the Group as an Administrator. A Group may be Private or Public.  
**Joining Groups** All public Groups are listed in a group catalog. Users may join a public group simply by pressing a "Join" button associated with that Group.  To join a private Group, an Administrator of the group must "Invite" a User.  Each User will have a list of zero or more pending Invitations - they may accept the invitation and this become a member of the Group.  They may also "Decline" the invitation, which removes it with no other action taken.
**User Visibility** Users can search for other users by name. A User can "Send Connection Request" to any user appearing in the search. That user will see active Connection Requests in a "Pending Actions" display that groups both Group Membership Invitations and Connection Requests.
**Jump Log Visibility to other users** all their Jump Records marked "Visible to Connections" become reviewable to members of a Group where they are a member.

## Device Management and "Factory Initialization"

**Device ID and Device Name** Each device will be assigned a unique Bluetooth ID. Details of how this will be allocated will be decided later. The Bluetooth name of the device will be "Tempo-BT-xxxx" where "xxxx" is the last four hex digits of the assigned Bluetooth ID.  For device "Factory Initialization", the device is first Flashed with application code and then powered up.
**Device Database** Devices may be in one of three states:
    - **Unprovisioned** - the device has been flashed  but has not been assigned a unique Bluetooth ID yet. It communicates on Bluetooth with the name "Tempo-BT-unprovisioned".
    - **Provisioned** - a Unique ID has been assigned and is stored in NV memory but the device has not been assigned to a User. [on the device, when a provisioning operation is complete, the device will rapidly (2Hz) flash the RGB LED Blue for ten seconds as an extra indication of which device was just provisioned.]
    - **Assigned** - the device has been assigned to a user.  The UUID or the user along with the "nextJumpNumber" are both stored in a uinfo.json file in the root directory of the SD Card.
**Administrator Role and Device Management** An User having the Administrator role, will have a "Device Management" Menu item available. Selecting that will take the user to a "Device Management" page.  The page will list all known devices and all freshly flashed but "Unprovisioned" devices (these will be discovered and recorded by the app's Bluetooth Service, which will be described later). A Device is considered "Provisioned" once it is assigned to a specific user.  A set of menu items (exposed via a "kebob" icon on each Device) on each Device will allow the device to be "Assigned to User", "Initialize", "Unprovision"ed, or "Blink" (Rapid blink the RGB LED amber for ten seconds). Each device on the display will have an "On-line" status, indicating that it has been detected in the last 5 minutes by the Bluetooth Service.  Devices must be on-lin to be assigned to a user or unprovisioned.  When being assigned, the Administrator selects the target User for assignment and also has the opportunity to set a "Next Jump Number". If this value isn't entered, it defaults to 1.

## Log Discovery and Upload Service

### General Description
A Bluetooth-capable process will run continuously on the application server.  It will continuously scan for "Tempo-BT" devices via BLE and maintain a table of all [Tempo devices](https://github.com/rrainey/tempo/tree/main/zephyr/tempo-bt-v1) it detects. Where a named Tempo-BT device shows up that has not been "seen" in over DISCOVERY_WINDOW (configurable, default: 300) seconds, the service will query the device for any log files that it has not successfully uploaded. It can detect this by storing the on-device pathname of the log file with the pathnames present on the device. Any files which have not previously been uploaded should be transferred to the server as new Jump Log records. The User ID metadata from the device should be used to determine which User ine the application database that the Log will be bound to (this get/set User UUID capability remains to be added to the device firemware).  This BLE scanning will be continuous.  After first detection, the device will be marked a "On-line". If it isn't detected by polling for over DISCOVERY_WINDOW seconds, it's status is updated to "Offline".

### Preliminary Jump Analysis and Grouping New Uploads into Formation Jumps

Newly arriving jump log records will be queued for analysis. The queue is determined by querying all Log records that have a NULL "initialAnalysisTimestamp", ordered by creation timestamp (newest first). Each record is analyzed serially at the server by a periodically running worker job.  the worker wakes up every 30 seconds, processes all jumps in the queue, then sleeps for another 30 seconds before reactivating.

#### Initial Analysis

When a new log file is processed by the worker, the data stream will be analyzed to extract or estimate several useful pieces of information:
- time offset for exit (estimated, seconds, relative to start of log) - sustained rate of descent over 2000 fpm for 1 second.
- time offset for parachute activation (estimated,seconds, relative to start of log) - estimated by first significant vertical deceleration (0.25g for 0.1 seconds for rough draft purposes)
- time offset for parachute deployment (seconds, relative to start of log) - first rate of descent below 2000 fpm after being in freefall
- time offset for landing (seconds, relative to start of log) - rate of descent <100 fpm for 10 seconds
- estimated exit timestamp (UTC)
- GNSS position (lat/lon) at estimated exit time.

These data items will be recorded in the Jump Log record.

#### Identifying Formation Jumps

The log start time should be compared with that of all other jump logs.  If the start time of the jump is within 120 seconds of any other jump, those jumps will be logically grouped into a **Formation Skydive**. The log records for any Formation Skydive will be visible to all Users who participated in the jump (and participation is determined by the presence of their own log record for that jump). The Log Records for a Formation Skydive will accumulate as log records for different devices are uploaded.  Eventually all pertinent logs will be uploaded and the Formation Skydive will reflect available data to all participants in the jump.

## Jump Review

### Formation Skydive Review

The (GNSS) position and pressure altitude data for each jumper will be used to render a "movie" of the skydive. A specific jumper will be designated as the "base" skydiver.  All other jumper locations and relative altitude differences will be plotted relative to this base jumper. The +X axis for the "Formation Frame" will be the Forward ground track of the jump aircraft. +Z is Up, and +Y maintains a right-hand coordinate system for the "Formation Frame".  A data set is then generated based on each log, translating the GPS lat/lon information into X/Y positions and Z locations  will be based on pressure altitude difference (cartesian units selectable as feet or meters).  These points can then be plotted using a rendering box that can be caged to a vertical "god's eye" view, caged looking  at the base from -X, or manually rotated to get different vantage points (left mouse down rotates the frame, scroll wheel zooms in and out - always centering on the designated base jumper). Reverse/Pause/Play/Fast-Forward controls will be present and allow for better interactive control in a debrief. A legend will depict the base jumper's fall rate (expressed in mph) and the altitude expressed as ft AGL.

### Fall Rate Performance Assessment
A Jumper's fall rate is governed by many factors simultaneously. All tother factors being equal, heavy jumpers fall faster. A jumper can select different jump suit styles, which will affect drag. And local air density will affect fall rate - and Standard Atmosphere air density will vary based on altitude and is also affected by both temperature and humidity.

The aerodynamic force acting on a body in freefall can be expressed as:

$$ F = 1/2 C_D \rho v^2 $$

Where $ C_D $ is the coefficient of Drag and $ \rho $ is air density.

For non-accelerating motion, the vertical force ($F$) will be equal to the jumper's weight ($W$), so:

$$ W = 1/2 C_D \rho v^2 $$

In many ways, a successful formation skydive will depend on matching the fall rates of all the participants.  Finding matched fall rates is a trial and error process today.  Our goal is to give jumpers solid guidance on how their fall rate range compares with an "average" jumper. A skydiver can control their fall rate relative to other jumps through changes in their body position. "Get big and de-arch" to go slower.  "Get small or arch hard" to go faster.  

We propose designing a "Fall Rate Baseline" Dive Flow to gather data about a jumper's fall rate range: the jumper ride the plane to full altitude, normally around 13,000 feet AGL, and exits solo.  The jumper "gets big" counting to fifteen, then "gets small" and counts to fifteen again. They repeat this alternating sequence down to their deployment altitude.  This should give us a good data set to evaluate their slowest and fastest belly-to-earth fall rates.

The rate of descent can be evaluated from the fall rate of change in altitude (which, in turn, is based on air pressure sampling). For analysis, this fall rate should be adjusted by computing looking up the air density for the given altitude. Air density will change based on the density lapse rate of the Standard Atmosphere - air is thinner at higher altitudes, so - al other factors being equal - a jumper will fall faster at higher altitudes. We propose that a correction can be applied along the descent to "normalize" the fall rate to correct for the local air density to develop a "normalized fall rate" reading which can be plotted.  We can analyze the plot to locate the period of faster and slower falling - and withing each of those intervals take perhaps samples from the stable middle section of each to develop a max/min range for fall rate.  That range could then be visually compared against a predetermined rage for an "average jumper" to give the skydiver feedback on how they compare - and help them select to either alter their jumpsuit configuration or perhaps wear weights when jumping.  The min / max fall rates used in this depiction should be tunable as system system settings, with the defaults being 110 and 130 mph, respectively.

## Lending a Device

Device Lending will introduce the concept of a **Proxy User**.  Where a User lends a device to someone who doesn't yet have a app User account, a Proxy User will be created.  A Proxy User is visible to Users in the same way that a full User account is visible.  Jump log data will be associated with the Proxy User in the same way that it is associated with an Account-holding User - Prox Users and their data will be visible to the User who created the Proxy User.  Given all that, a Proxy User is probably best implemented as a special state or flag associated with a User object.

A User will want to be able to lend a device to another skydiver for one or more jumps.  This will be called **Lending**. A "Lend My Device" link will be exposed on the User's Home page. It links to a page where the User can select the device to be lent (this User may "own" more than one device), specify the User to lend to, and the lending period:

- A User may own more than one device; a dropdown box allows the user to select which device they intend to lend.
- A widget will allow for easy text search and selection of existing users.  This widget will also allow for a "Create Proxy User.." function. The lending User adds the Full Name of the new User,
- The lending period can be "one jump", "any number of jumps", or "until I reclaim the device". This information will be stored in the Device's object record and used to potentially automatically "return"

A person with a Proxy User account created on their behalf may claim their account.  If a User has created a Proxy User, they can "Help Someone Claim their Account". Their list of Proxy Users who they have lend a device to is shown.  They select a User.  The application will generate one-time "Claim Account" URL - this is a URL to "Create Account" Page specifically to change an existing Proxy User account into a regular account along with a parameter specifying the Claim Account record - that, in turn, specifies the UUID of the Proxy Account.  When a Proxy User is selected on this page, a QR Code corresponding to the "Claim Account" url will be displayed. The person who'd like to claim the account can use their phone's camera to capture the URL and claim their account.

## Data Model Notes

Here's notes about the minimal fields we'd expect to have present in each application data object.

### Users
- A UUID to uniquely identify the User (auto generated)
- Full Name
- Profile image (blob, 2MB limit)
- Profile image MIME content type (e.g., "image/jpeg", "image/png")
- An "isProxy" flag
- Where it represents a Proxy User, a reference to the "proxyCreator" user
- creation timestamp UTC
- last active timestamp UTC
- a "User Slug" - used to form the url of the user; must be unique (automatically generated to define a URL for the group; a lowercase, whitespace-mapped version of the friendly name; e.g. "Bill Jones" should be mapped to "bill-jones"; when a user is created and a "slug" already exists, the generated slog will have a "-nnn" appended, where nnn is a randomly generated decimal number)
- Assigned User Roles

### User Roles
Currently the only defined user role is (system) "Administrator"
- UUID of User (indexed) 
- Role enumeration **currently** only Administrator is defined.

Together, these two elements form a composite primary key for the table.

### Groups
- A UUID (auto generated)
- Friendly name
- a "Slug" (automatically generated to help define a URL for the group; a lowercase, whitespace-mapped version of the friendly name; e.g. "Camp Casual Fridays" should be mapped to "camp-casual-fridays"; when a group is created and the mapped "slug" already exists, the generated slug will have a "-nnn" appended, where nnn is a randomly generated decimal number)
- Map of Users (with isAdmin flag)

### Jump Log
= a UUID (auto generated)
- Log Start Timestamp (UTC)
- Estimated Exit Lat/Lon (possibly null)
- estimated exit altitude (feet, possibly null)
- owning User UUID
- Jump Number for the user
- Log contents (long text or blob, whatever is most efficient for 8MB log files)
- time offset for exit (estimated, seconds, relative to start of log) - sustained rate of descent over 2000 fpm for 1 second.
- time offset for parachute activation (estimated,seconds, relative to start of log) - estimated by first significant vertical deceleration (0.25g for 0.1 seconds for rough draft purposes)
- time offset for parachute deployment (seconds, relative to start of log) - first rate of descent below 2000 fpm after being in freefall
- time offset for landing (seconds, relative to start of log) - rate of descent <100 fpm for 10 seconds
- User editable markdown text notes describing the jump
- the SHA-259 hash of the Jump log contents
- a "visibleToConnections" Flag - defaults to True when a log is uploaded, but the owning user can edit this value.
- app record creation timestap (UTC) - timestamp of record creation
- initialAnalysisTimestamp - the date/timestamp of completion of initial analysis.
- initialAnalysisMessage - text; any unusual conditions or errors encountered during analysis are logged here.

### Formation Skydive
- a UUID (auto generated)
- A Map of a Jump Logs associated with this Formation skydive (within each map entry is a "isVisibleToOthers" flag; this flag defaults to True, but can be reset by the owning User to make the Jump data invisible to others).
- UUID of the Jump log used as the "Base" jumper (editable by anyone participating in the Skydive)
- date of the jump (local time zone) - derived from the start time from the first two Jumps that comprised the skydive.

The data represented by this Formation Skydive and the log data for all jumpers is visible to all participants in the Jump (after taking int account the "isVisibleToOthers" flag previously mentioned)

### Devices
- An app assigned UUID (for internal tracking purposes) (auto generated)
- Owner User (possibly null)
- Lent-To User (possibly null)
- On-line status
- Device State: Unprovisioned, Provisioned, Assigned
- Device UID *(possibly null)
- Device Bluetooth Name
- Device Bluetooth ID
- Lending Status: Lent-till-reclaimed, one-jump-only

### User Invitation
- UUID of User invitation object (auto generated)
- Expiration timestamp, UTC - generated invitations expire 30 days after being generated
- Proxy User UUID - the id of the user being invited to join.

User Invitations are only meaningful when a User has lent their device to someone for a jump and wants to allow that user to register and gain direct access to the data.  Otherwise, the new user can just register by visiting the login page.

## Page mapping

- `/` just a redirect to the login page or /home if logged in, for now.

- `/login`

- `/register`

- `/accept-invitation/[invitation-id]`

- `/profile` - editable user and account settings. Profile Photo. Change password.

- `/home` - a user specific home page. A left-side navigation bar (Groups - the list of Groups the user is a member of, Devices, including status of "loaner" devices, Settings, Logout). Jump review rendered in the main (center) window. Right side blocks include "Formation Jumps", "My Jumps", "Summary" (Summary on the selected jump; date/time (local), exit altitude) - for "solo" jumps, jump number, estimated deployment altitude, freefall time (sec), average fall rate (mph)

- `users/[user-slug]`

- `groups/[group-slug]`

- `review/fs/[fs-id]` - a dedicated review page depicting information for the specified formation skydive. Navigation minimized and information display simplified to essentials. Dots for each jumper with a succinct data block with Name, distance from the base (feet), closure rate to the base (fps & mph). Right hand blocks for Jumper list, and Base Info (fall rate; calibrated fall rate)

## Technology Stack
Use Next.js, Typescript, Mantine for core UI elements, recharts for charts and graphs, d3 for 3D visualization, Prisma for ORM, and a local instance of Supabase for database storage. Avoid using Tailwind CSS for styling, but instead use Mantine's organic styling extensibility.

The application should be designed for deployment on Ubuntu 24.04 on a Raspberry Pi 5.

The application will be deployed at the local dropzone facility to provide for Bluetooth connectivity to the logging devices.  The Bluetooth functions should be provided through the most reliable Bluetooth stack available that can provide all needed interaction functions - I'd prefer to use BluZ directly from Typescript, but using mcumgr via shell callouts might be an option as well.

## Theming

The application should use these colors, aiming for a overall Dark Mode color scheme.

color-1 #002233 (primary background)
color-2 #11425d (secondary backgrounds)
color 3 #ddff55 (emphasis font/line color)
color-4 #c0d6ea
color-6 #c5c0c9 (text foreground, primary line drawing/graphics)
color-7 #f6f2e8
color-8 #f04848 (flag unsafe values or conditions on the graphical depictions)
color-9 #855bf0 (alternate emphasis font/line color)

Use the Mantine default per-platform font choices.

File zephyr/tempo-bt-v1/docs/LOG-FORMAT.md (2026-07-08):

# Tempo-BT Log File Format

A Tempo-BT log (`flight.txt`, one per logging session, stored at
`/logs/<YYYYMMDD>/<SESSIONID>/` on the device's primary storage) is an extended
NMEA-sentence text file: [NMEA 0183](https://en.wikipedia.org/wiki/NMEA_0183)
standard GNSS sentences interspersed with the application-specific sentences
described below. Lines are CRLF-terminated.

A session begins when logging starts — by push-button (`manual_start`), by BLE
command, or automatically when the device detects the aircraft climbing
(`takeoff_detected`) — and ends on manual stop, BLE command, or automatically a
short time after the jumper reaches the ground.

This document describes the format emitted by **Tempo-BT firmware v1.x**
(`$PVER` format versions 110 and later). The format descends from the earlier
Dropkick logger; the legacy Dropkick format (versions 0xx) is documented in the
Dropkick repository. A version-history table appears at the end of this
document.

## Time bases

Some NMEA sentences include a UTC timestamp computed by the GNSS receiver. The
device's native clock is its uptime in milliseconds (an unsigned 32-bit count
since boot, written as "device-ms" below; the Dropkick heritage called this
`millis()`). Both time values appear in a log file, and the two timelines are
correlated using the `$PTH` sentence described below.

## NMEA Checksums

All sentences end with a three-character NMEA checksum sequence (`*HH`, where
`HH` is the hex representation of the checksum byte). Checksums are omitted
from most examples below for clarity.

## GNSS Sentences

The u-blox GNSS receiver contributes standard sentences with the `$GN` talker
prefix:

| Sentence | Rate | Notes |
|---|---|---|
| `$GNGGA` | 1 Hz normally, **10 Hz in jump mode** | position/fix; each GGA is immediately followed by a `$PTH` |
| `$GNVTG` | 1 Hz normally, **10 Hz in jump mode** | course/speed over ground |
| `$GNRMC` | 1 Hz (always; does **not** increase in jump mode) | carries the UTC **date** — the only sentence that does. Emitted since format version 112; **version-110 logs contain no RMC**, so tools must derive the date elsewhere (e.g. the session directory name). |
| `$GNGSA` | *planned — not currently emitted* | DOP/active satellites |

## $PVER Record

A single instance appears as the first sentence of each log, documenting the
firmware that created the file. The version number's "hundreds" digit
designates the board family: 1xx = Tempo, 0xx = the legacy Dropkick. (An
imperfect scheme, retained for compatibility.)

### Comma-separated Fields

| Description | |
|---|--|
| $PVER | Record identifier |
| id string | human-readable firmware identification |
| version number | integer format version; 1xx = Tempo |

### Example

`$PVER,"Tempo V2 1.4.0 (fa93d6d-dirty)",114*72`

## $PSFC Record

Follows the `$PVER` sentence. Records the estimated surface altitude of the
takeoff area, computed from static air pressure assuming a
[standard atmosphere lapse rate](https://en.wikipedia.org/wiki/Atmospheric_pressure).
Subtract this value from `$PENV` altitude reports to estimate height above
ground level (AGL).

### Comma-separated Fields

| Description | |
|---|--|
| $PSFC | Record identifier |
| estimated surface altitude | feet, MSL (reflects pressure sampled at the device) |

### Example

`$PSFC,650*19`

## $PST Record

Records logger state-machine transitions. Useful for isolating segments of the
jump during analysis — in particular, the transition **to `JUMPED` marks
freefall detection (exit)**.

The logger states are `IDLE`, `ARMED`, `LOGGING`, `JUMPED`, and `POSTFLIGHT`.
A session's first `$PST` is normally the transition into `LOGGING`; the reason
field is free text (observed values include `manual_start`,
`takeoff_detected`, `freefall_detected`, `manual_stop`).

> Heritage note: Dropkick used a 3-field form (`$PST,<ms>,<newstate>`) with
> states `WAIT/FLIGHT/JUMPING/LANDED1`. Tempo-BT has always used the 5-field
> transition form below.

### Comma-separated Fields

| Description | |
|---|--|
| $PST | Record identifier |
| device-ms timestamp | time of state change in milliseconds |
| from state | state being left |
| to state | state being entered |
| reason | free-text trigger description |

### Examples

```
$PST,1037,ARMED,LOGGING,takeoff_detected*63
$PST,813987,LOGGING,JUMPED,freefall_detected*51
$PST,1096343,JUMPED,IDLE,manual_stop*37
```

## $PIMU Record

Logs inertial data from the ICM42688-V IMU, reported in Case Axes (body axes),
shown below.

### Comma-separated Fields

| Description | |
|---|--|
| $PIMU | Record identifier |
| device-ms timestamp | time of sample in milliseconds |
| X-accel | meters per second squared |
| Y-accel | meters per second squared |
| Z-accel | meters per second squared |
| X-rate | rotation rate, radians per second |
| Y-rate | rotation rate, radians per second |
| Z-rate | rotation rate, radians per second |

Tempo Frames
Tempo board axes, including the Case (or Body) Axis definitions

### Example

`$PIMU,1396,-1.21,9.73,-3.75,-0.0701,-0.0653,-0.0075*07`

## $PIM2 Record

The real-time orientation of the jumper expressed as a
[quaternion](https://en.wikipedia.org/wiki/Quaternions_and_spatial_rotation).
One `$PIM2` immediately follows each `$PIMU`.

The application maintains this orientation quaternion from a 200 Hz sample
stream inside the IMU pipeline (logged at the `$PIMU` rate). A startup value
of [1,0,0,0] is used, and the quaternion accumulates all body-axis rotation
from that original orientation. Transforming it into a world frame
(North-East-Down, for example) remains analysis-side work.

### Comma-separated Fields

| Description | |
|---|--|
| $PIM2 | Record identifier |
| device-ms timestamp | time of sample in milliseconds |
| W | quaternion w component, non-dimensional |
| X | quaternion x component, non-dimensional |
| Y | quaternion y component, non-dimensional |
| Z | quaternion z component, non-dimensional |

### Example

`$PIM2,13925127,1.0000,0.0000,0.0000,0.0000`

## $PENV Record

Logs static pressure from the
[BMP390 sensor](https://www.bosch-sensortec.com/products/environmental-sensors/pressure-sensors/bmp390/)
and a derived standard-day altitude.

### Comma-separated Fields

| Description | |
|---|--|
| $PENV | Record identifier |
| device-ms timestamp | time of sample in milliseconds |
| static air pressure | hPa |
| estimated altitude | from static pressure assuming a Standard Day; feet, MSL |
| VBATT voltage | **always -1.00 on Tempo-BT** (battery voltage is not monitored on V1 hardware; the field is retained for Dropkick compatibility) |

### Example

`$PENV,1286,987.85,701.05,-1.00*3A`

## $PTH Record

Correlates device-ms timestamps with the GNSS UTC clock in standard NMEA
sentences. **One `$PTH` immediately follows each `$GNGGA`**; its timestamp is
the device-ms at the arrival of the first character of that GGA sentence.
(`$PTH` follows the GGA only — not VTG or RMC.)

To convert a device-ms event time to UTC: take the GGA preceding the event,
its paired `$PTH`, and compute `event_utc = gga_utc + (event_ms - pth_ms)`.

### Example

```
$GNGGA,134316.00,3327.50347,N,09622.62352,W,1,12,0.59,258.0,M,-25.6,M,,*71
$PTH,1364*60
```

## $PMAG Record (devices with MMC5983MA magnetometer)

Logs calibrated magnetometer data. Only emitted when `mag_mode > 0` and
calibration is valid. Values are in the device body-axis frame after hard/soft
iron correction. Earth's magnetic field magnitude is typically 25–65 µT.

### Comma-separated Fields

| Description | |
|---|--|
| $PMAG | Record identifier |
| device-ms timestamp | time of sample in milliseconds |
| X-mag | calibrated magnetic field X, µT |
| Y-mag | calibrated magnetic field Y, µT |
| Z-mag | calibrated magnetic field Z, µT |

### Example

`$PMAG,13925127,23.50,-12.30,45.60`

## $PRMG Record (USB calibration streaming)

Streams raw magnetometer readings during calibration mode (BTN2 short press
with USB connected). Values are SET/RESET corrected but NOT hard/soft-iron
calibrated. Used by the Python calibration tool (`mag_cal.py`) to collect
samples for ellipsoid fitting. Appears on the USB CDC-ACM stream, not in log
files.

### Comma-separated Fields

| Description | |
|---|--|
| $PRMG | Record identifier |
| device-ms timestamp | milliseconds since boot |
| raw X | raw X count, signed 18-bit (16384 counts/Gauss) |
| raw Y | raw Y count, signed 18-bit (16384 counts/Gauss) |
| raw Z | raw Z count, signed 18-bit (16384 counts/Gauss) |
| temperature | die temperature, °C |

### Example

`$PRMG,13925127,8192,-4096,12288,25.3`

## $PCMD / $PRSP Records (USB command protocol)

A bidirectional command/response protocol over the USB CDC-ACM interface.
Commands are only accepted during magnetometer calibration streaming mode.
These sentences do not appear in log files.

### Command Format (Host → Device)

`$PCMD,<verb>[,<arg1>,<arg2>,...]*HH\r\n`

### Response Format (Device → Host)

`$PRSP,<verb>,<result>[,<data>,...]*HH\r\n`

### Available Commands

| Command | Description |
|---|---|
| CAL_GET | read current NVM calibration data |
| CAL_SET | write calibration data to NVM (6 fields: offset_x, offset_y, offset_z, scale_x, scale_y, scale_z) |
| MODE_GET | read current mag_mode setting |
| MODE_SET | set mag_mode (0=disabled, 1=factory, 2=NVM calibrated) |

### Examples

```
$PCMD,CAL_GET*27
$PRSP,CAL_GET,1,-234,567,-89,32100,33200,31800*4F

$PCMD,CAL_SET,-234,567,-89,32100,33200,31800*1A
$PRSP,CAL_SET,OK*3B

$PCMD,MODE_SET,2*5C
$PRSP,MODE_SET,OK*2E
```

## Sentence Reporting Rates

| Sentence Type | Reporting Rate |
|:---:|:---|
| PVER | first line of the log file |
| PSFC | follows the PVER sentence |
| GNGGA, GNVTG | 1 Hz normally; 10 Hz in jump mode |
| GNRMC | 1 Hz (unchanged in jump mode); since version 112 |
| GNGSA | planned — not currently emitted |
| PTH | one, immediately following each GGA |
| PIMU | 20 Hz |
| PIM2 | follows each $PIMU sentence |
| PENV | 4 Hz |
| PST | at each logger state change |
| PMAG | 20 Hz (when magnetometer enabled and logging) |
| PRMG | 20 Hz (USB calibration streaming mode only; not in logs) |
| PCMD / PRSP | on-demand (USB calibration streaming mode only; not in logs) |

## Format Version History

| $PVER version | Firmware | Changes |
|---|---|---|
| 110 | Tempo V2 1.0.0 | Tempo-BT baseline: GGA/VTG + PTH, PIMU/PIM2 (20 Hz), PENV (battery always -1.00), PSFC, 5-field $PST. **No $GNRMC** — logs carry no in-band UTC date. |
| 112 | Tempo V2 1.2.0 | Added `$GNRMC` (1 Hz), providing the UTC date in-band. |
| 114 | Tempo V2 1.4.0+ | `$PMAG` available when `mag_mode > 0`; settings gained `mag_mode`. |

*(Rates and behaviors above verified against real session logs from each
version era, 2026-07-08.)*

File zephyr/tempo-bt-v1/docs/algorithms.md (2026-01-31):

# Tempo-BT V1 - Flight Detection and State Machine Algorithms

## Overview

This document describes the algorithms used in the Tempo-BT V1 Zephyr implementation for flight phase detection and automatic state management. The system uses a combination of barometric pressure sensing and accelerometer data to detect takeoff, freefall, and landing events.

## State Machine

### State Definitions

```c
typedef enum {
    LOGGER_STATE_IDLE,       // Device idle, not monitoring
    LOGGER_STATE_ARMED,      // Monitoring for takeoff
    LOGGER_STATE_LOGGING,    // In-flight, recording data
    LOGGER_STATE_JUMPED,     // Freefall/canopy descent detected
    LOGGER_STATE_POSTFLIGHT, // Post-flight processing
    LOGGER_STATE_ERROR       // Error condition
} logger_state_t;
```

### State Transition Diagram

```
                    ┌──────────────┐
                    │     IDLE     │
                    └──────┬───────┘
                           │ logger_arm()
                    ┌──────▼───────┐
              ┌────►│    ARMED     │◄────────────────────┐
              │     └──────┬───────┘                     │
              │            │ Climb rate > 200 ft/min     │
              │            │ for 3 consecutive seconds   │
              │     ┌──────▼───────┐                     │
              │     │   LOGGING    │                     │
              │     └──────┬───────┘                     │
              │            │ Freefall detected:          │
              │            │ • Baro: < -1000 ft/min 2s   │
              │            │ • Accel: < 0.6g for 500ms   │
              │     ┌──────▼───────┐                     │
              │     │    JUMPED    │                     │
              │     └──────┬───────┘                     │
              │            │ Low activity for 60s        │
              └────────────┴─────────────────────────────┘
                           │
              (6 min timeout in LOGGING also returns to ARMED)
```

### Transition Thresholds

| Parameter | Value | Description |
|---|---|---|
| `EXEC_TAKEOFF_CLIMB_RATE_MPS` | 1.016 m/s | 200 ft/min - triggers ARMED→LOGGING |
| `EXEC_FREEFALL_DESCENT_RATE_MPS` | -5.08 m/s | -1000 ft/min - triggers LOGGING→JUMPED (baro method) |
| `EXEC_FREEFALL_ACCEL_THRESHOLD_G` | 0.6g | Low-g threshold for freefall (accel method) |
| `EXEC_LOW_ACTIVITY_RATE_MPS` | 1.016 m/s | |200 ft/min| - low activity threshold |
| `EXEC_JUMPED_TIMEOUT_S` | 60s | Low activity duration to detect landing |
| `EXEC_LOGGING_ABORT_TIMEOUT_S` | 360s | 6 min low activity in LOGGING aborts session |

### Executive Function

The executive function (`logger_executive()`) runs every **250ms** and manages automatic state transitions. This faster interval (compared to the original 1s) enables more responsive freefall detection.

## Climb Rate Estimation

### Alpha-Beta Filter

The system uses an alpha-beta filter (also known as a g-h filter) for coupled altitude/velocity estimation from barometric pressure data. This approach provides better transient rejection than simple derivative-based methods.

**Filter Parameters:**
- `ALPHA_BETA_ALPHA = 0.15` - Position (altitude) correction weight
- `ALPHA_BETA_BETA = 0.005` - Velocity (climb rate) correction weight

These values provide approximately 1-2 second time constant for good transient rejection while maintaining reasonable responsiveness.

**Algorithm:**

```c
// Predict step: advance state using current velocity estimate
altitude_pred = altitude_est + climb_rate_est * dt;

// Update step: correct prediction using measurement residual
residual = measured_altitude - altitude_pred;
altitude_est = altitude_pred + ALPHA * residual;
climb_rate_est = climb_rate_est + (BETA / dt) * residual;
```

### Median Pre-Filter

Before the alpha-beta filter, a 3-sample median filter is applied to reject single-sample outliers in the barometric altitude measurements:

```c
filtered_altitude = median3(buffer[0], buffer[1], buffer[2]);
```

### Data Flow

```
Barometric       Median         Alpha-Beta        Executive
Altitude    ──►  Pre-filter ──► Filter       ──►  Function
(~50 Hz)         (3 samples)    (position +       (250ms interval)
                                velocity)
```

## Freefall Detection

The system implements two parallel methods for detecting freefall, with the accelerometer method providing faster response:

### Method 1: Barometric (Descent Rate)

- **Threshold:** Descent rate exceeds 1000 ft/min (5.08 m/s)
- **Confirmation:** 2 consecutive seconds (8 executive ticks)
- **Latency:** ~2 seconds from jump initiation

### Method 2: Accelerometer (Low-G)

- **Threshold:** Filtered acceleration magnitude < 0.6g
- **Confirmation:** 2 consecutive readings at 250ms intervals (500ms total)
- **Latency:** ~500ms from jump initiation

The accelerometer method triggers state transition to JUMPED significantly faster, allowing earlier capture of high-rate GNSS position data during freefall.

### Accelerometer Magnitude Filtering

The IMU service maintains an EMA-filtered acceleration magnitude when enabled:

**Filter Parameters:**
- Sample rate: 200 Hz (ICM42688 FIFO)
- `ACCEL_MAG_FILTER_ALPHA = 0.15` - ~33ms time constant

**Algorithm:**

```c
// Compute magnitude in g
magnitude_g = sqrt(ax_g² + ay_g² + az_g²);

// EMA filter update
filtered_magnitude = α * magnitude + (1-α) * filtered_magnitude_prev;
```

The filter is enabled when entering LOGGING state and disabled when logging stops, minimizing computational overhead during non-flight periods.

## Ground Altitude Tracking

### Continuous Sampling

During IDLE and ARMED states, the system periodically samples barometric altitude to maintain an accurate ground reference:

- **Sampling interval:** Every 5 minutes (300 seconds)
- **Storage:** Moving average maintained by baro service

### Initial Calibration

When arming, the current barometric altitude is captured as the initial ground reference if not already set.

## Takeoff Detection

Takeoff is detected by monitoring for sustained positive climb rate:

- **Threshold:** > 200 ft/min (1.016 m/s)
- **Confirmation:** 3 consecutive seconds (12 executive ticks at 250ms)
- **Result:** Automatic transition from ARMED to LOGGING

## Landing Detection

Landing is detected by monitoring for sustained low vertical activity:

- **Threshold:** |climb rate| < 200 ft/min (1.016 m/s)
- **Confirmation:** 60 seconds of continuous low activity
- **Result:** Automatic transition from JUMPED to ARMED

## GNSS Rate Management

The system dynamically adjusts GNSS update rate based on flight phase:

| State | GNSS Rate | Rationale |
|---|---|---|
| IDLE/ARMED | 1 Hz | Power conservation |
| LOGGING | 1 Hz | Sufficient for aircraft climb |
| JUMPED | 10 Hz | High-rate position capture during freefall/canopy |

## Timing Summary

| Component | Update Rate | Purpose |
|---|---|---|
| IMU FIFO | 200 Hz | Orientation tracking, accel filtering |
| Barometric | ~50 Hz | Altitude/pressure measurement |
| Alpha-beta filter | Per baro sample | Climb rate estimation |
| Accel magnitude filter | Per IMU sample | Freefall detection |
| Executive function | 4 Hz (250ms) | State transition decisions |
| Ground altitude sample | Every 5 min | Ground reference update |

## Implementation Files

| File | Purpose |
|---|---|
| `src/services/logger.c` | State machine, executive function, baro handler |
| `src/services/imu_icm42688.c` | Acceleration magnitude filter |
| `src/services/baro.c` | Barometric sampling, ground altitude tracking |
| `src/services/orientation.c` | IMU FIFO processing, quaternion estimation |

## References

- Alpha-beta filter theory: [PMC4179067](https://pmc.ncbi.nlm.nih.gov/articles/PMC4179067/)
- ICM42688 datasheet for accelerometer specifications

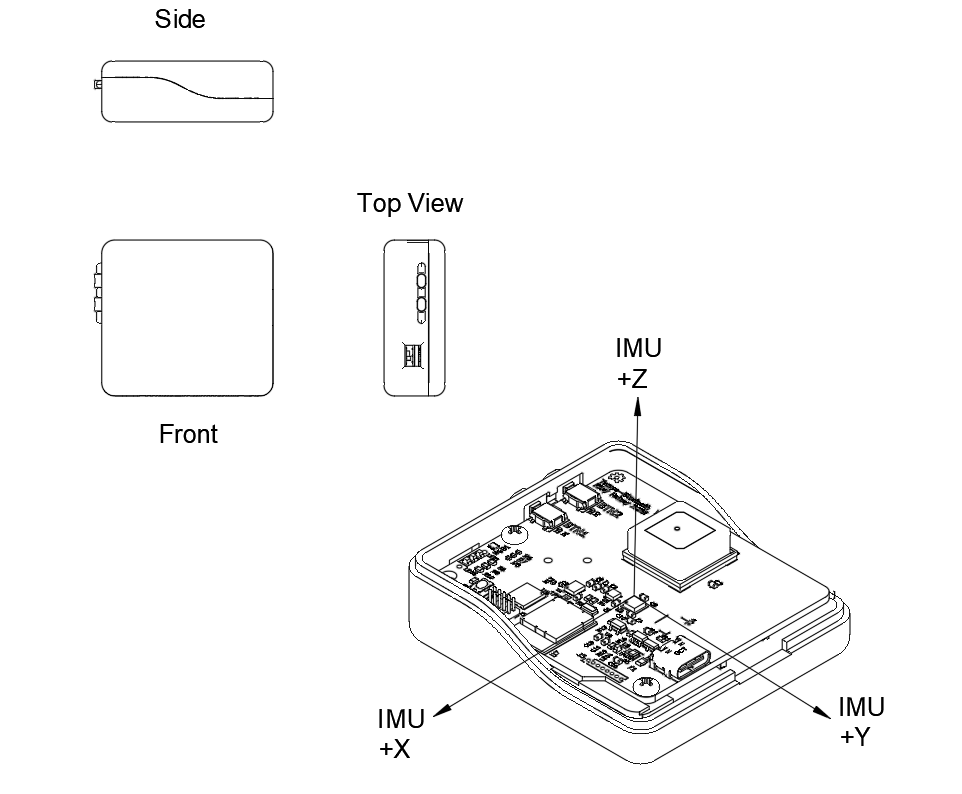
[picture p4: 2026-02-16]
images/Tempo-BT-V2-3-view-02.png

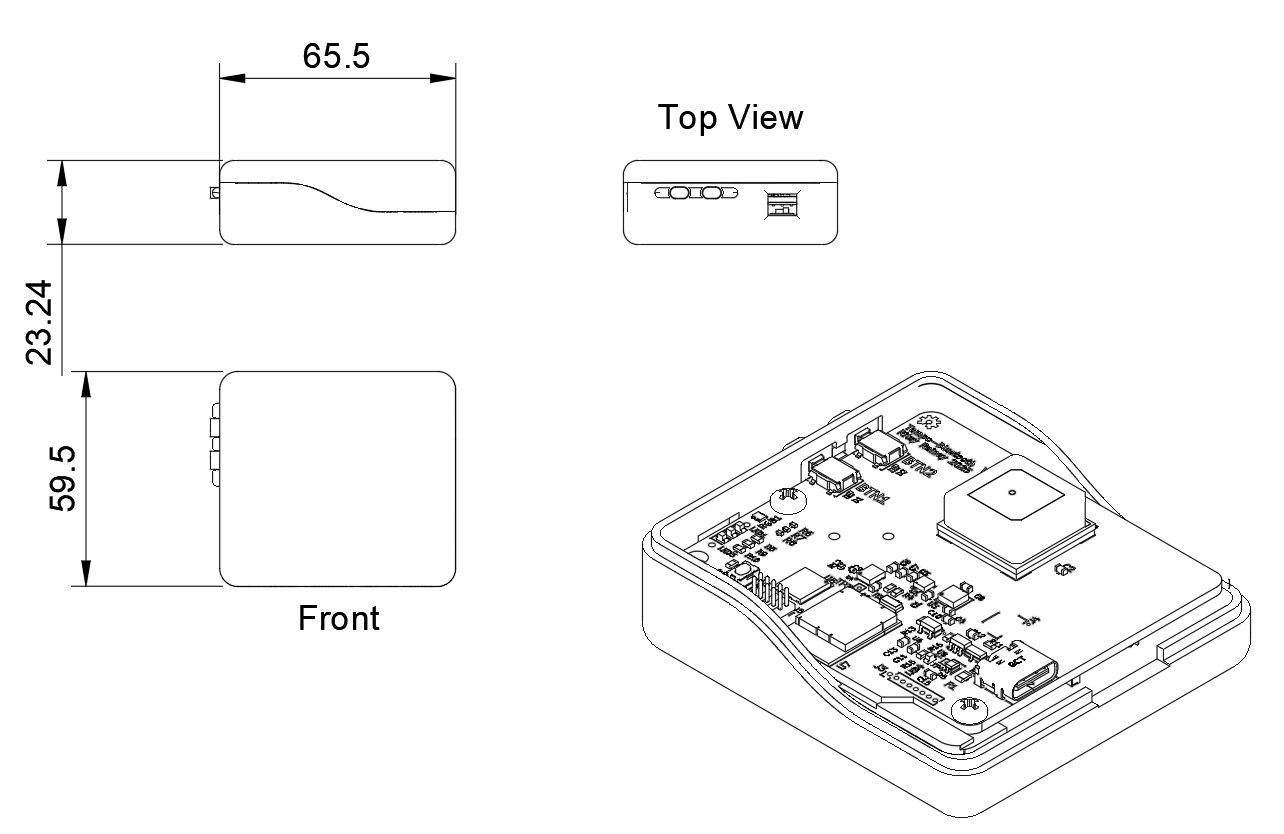
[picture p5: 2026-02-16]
images/Tempo-BT-V2-3-view.png

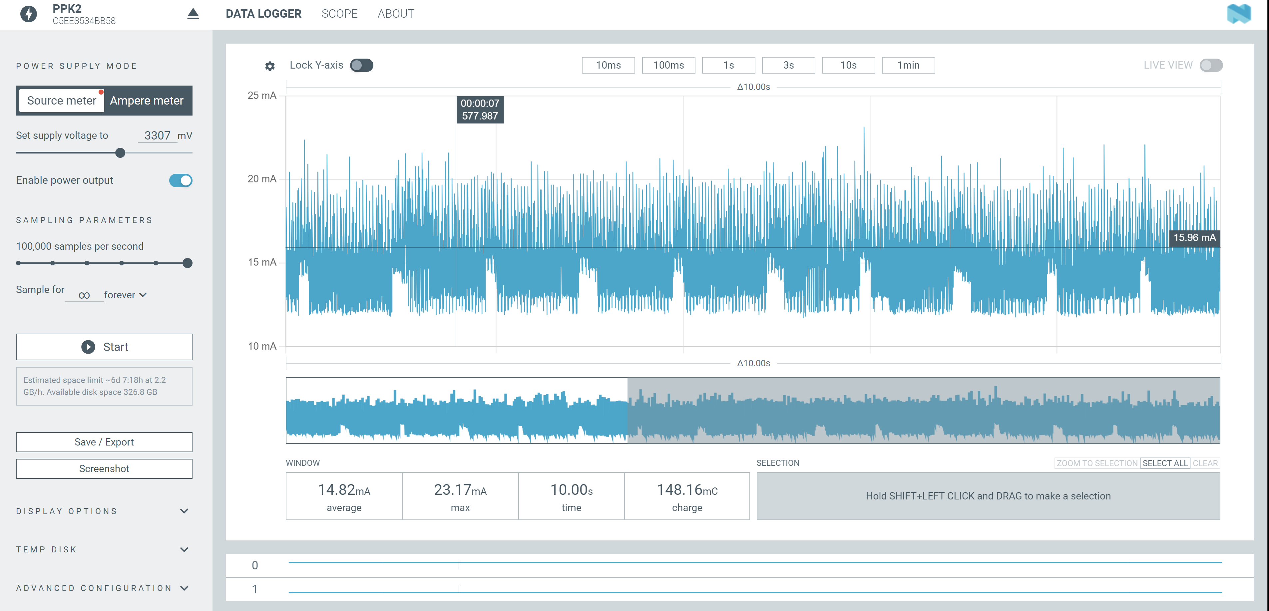
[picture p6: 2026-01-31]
images/ppk2-01.png

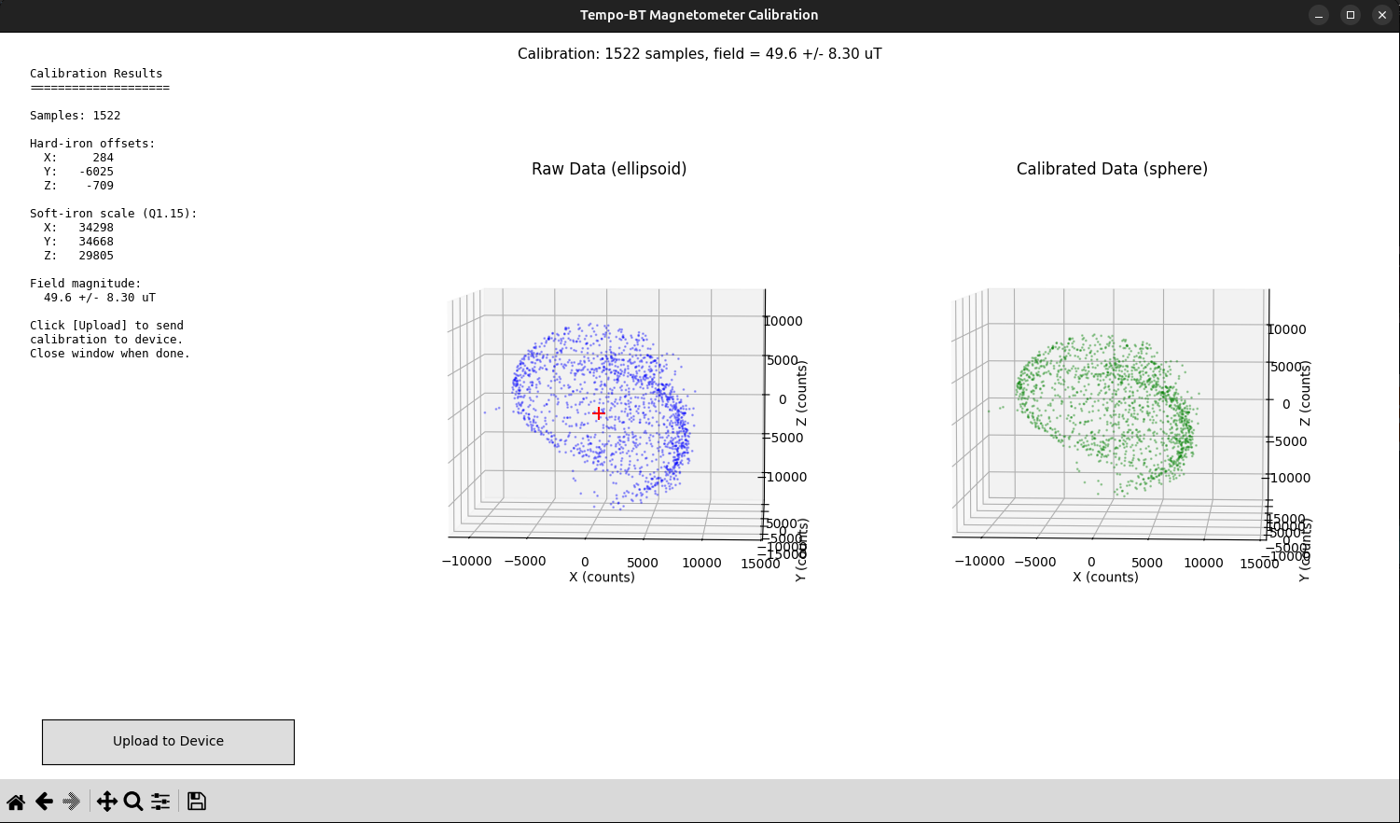
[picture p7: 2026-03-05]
zephyr/tempo-bt-v1/docs/mag-post-sampling.png

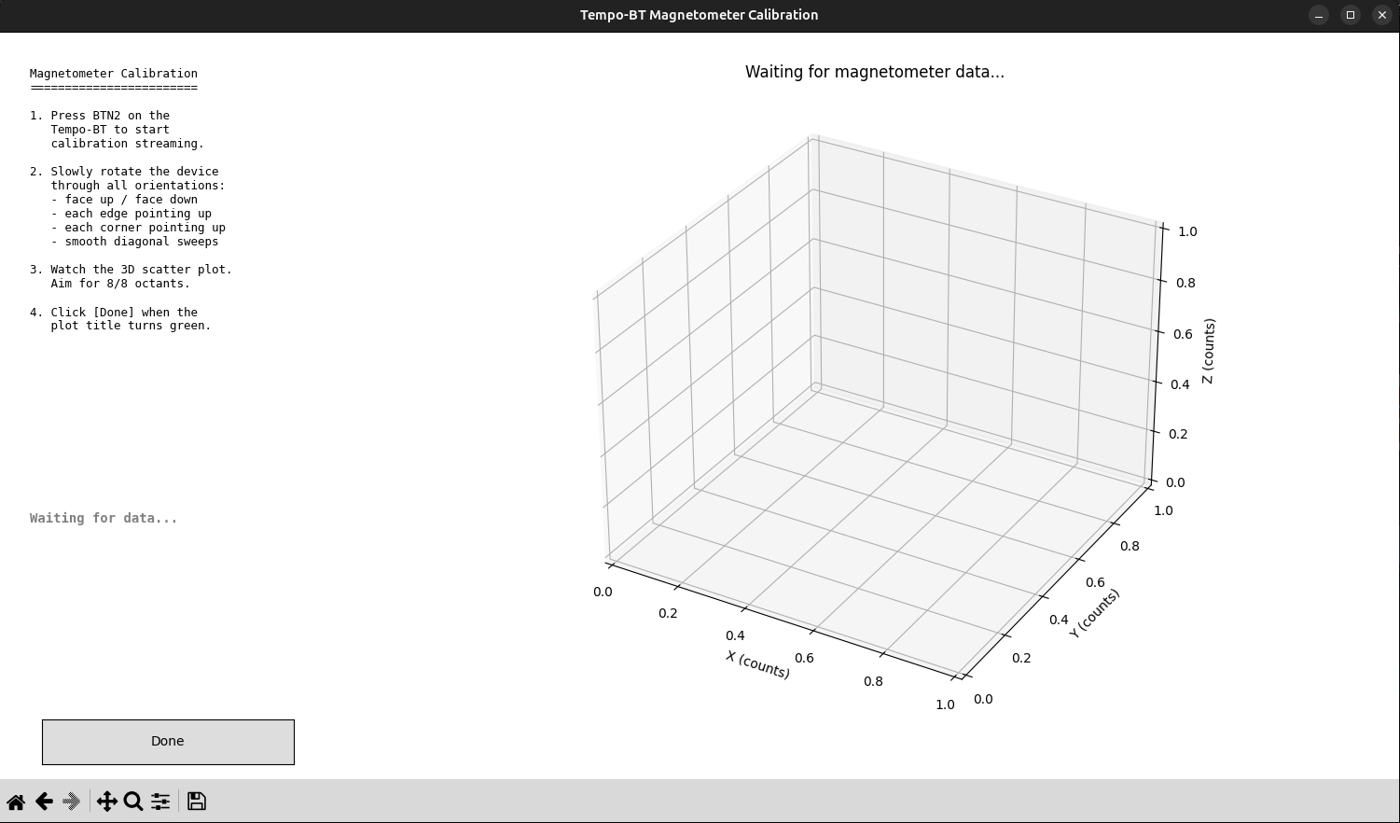
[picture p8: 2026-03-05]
zephyr/tempo-bt-v1/docs/mag-pre-sampling.png

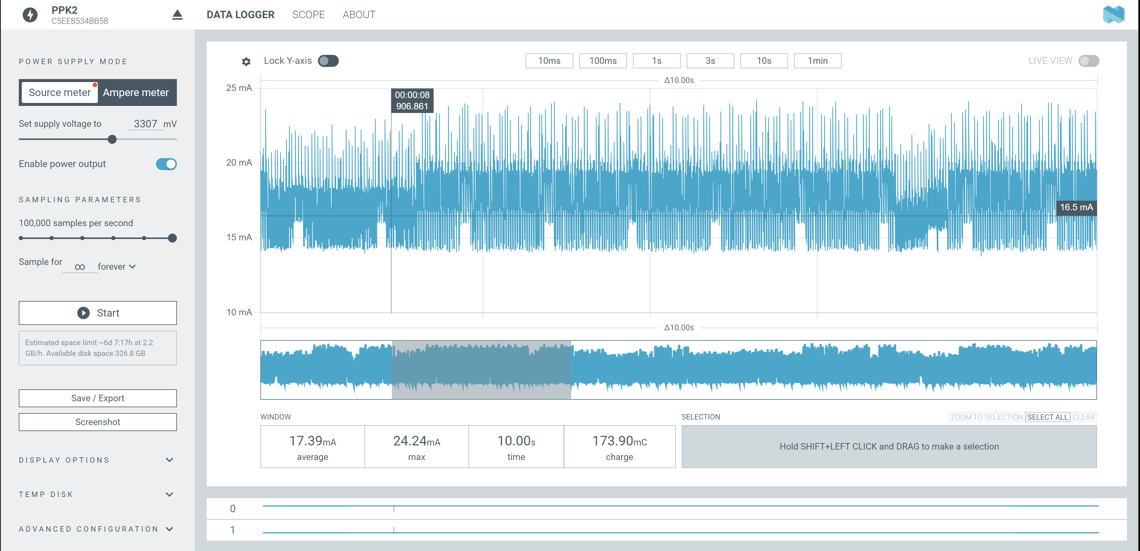
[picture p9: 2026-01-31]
images/ppk2-02.png

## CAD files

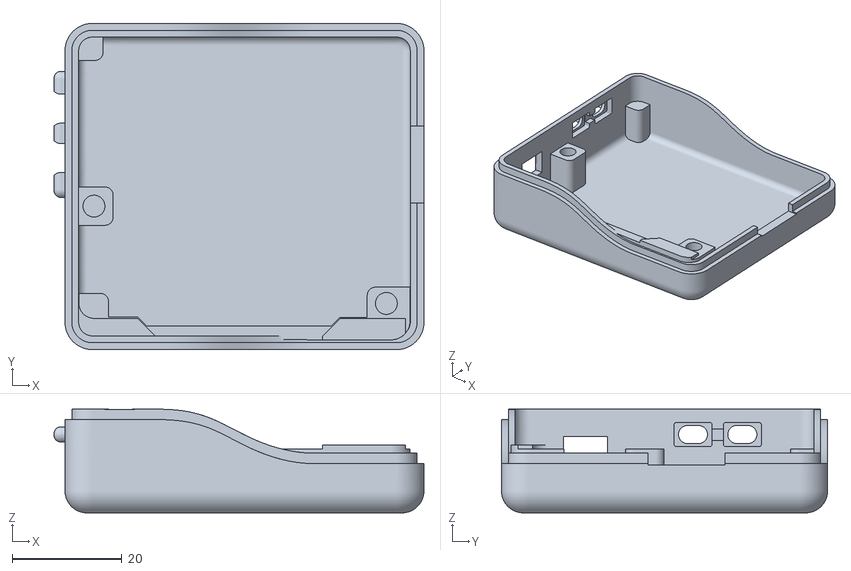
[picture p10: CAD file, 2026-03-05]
enclosure/Enclosure-Bottom.stl
67.5 x 59.5 x 18.9

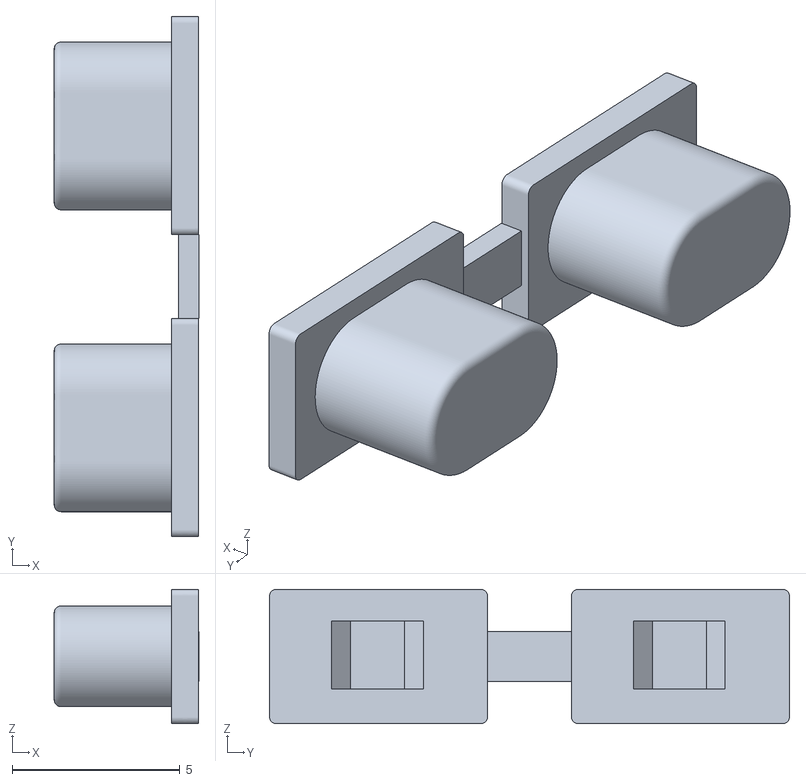
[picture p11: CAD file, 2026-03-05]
enclosure/Pushbuttons.stl
4.31 x 15.5 x 4.00

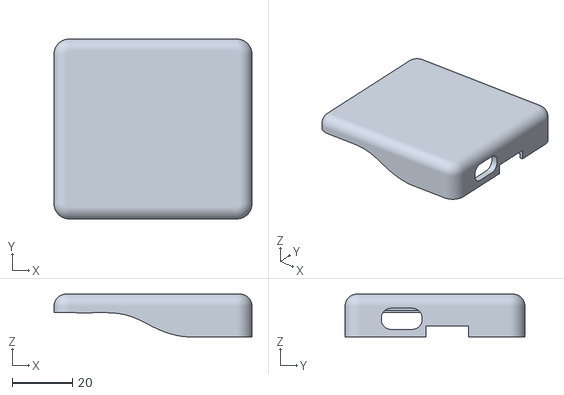
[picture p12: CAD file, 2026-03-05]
enclosure/Enclosure-Top.stl
65.5 x 59.5 x 14.2

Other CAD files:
enclosure/tempo-v2-enclosure.f3z

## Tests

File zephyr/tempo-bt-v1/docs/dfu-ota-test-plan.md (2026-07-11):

# BLE OTA DFU Verification Test Plan

**Status:** ✅ Executed & PASSED on devices `0004`, `0005`, `0006`, `0008` (2026-07-11) —
see §9. Draft plan retained below.
**System under test:** `tempo-bt-v1` firmware, MCUboot BLE OTA DFU path
**Goal:** Prove the existing BLE OTA DFU capability by upgrading a real device from
firmware **1.4.0 → 1.5.0** over Bluetooth, byte-for-byte trustworthy and repeatable,
using a command-line workflow.

> The README currently marks OTA firmware updates as *"not yet tested"*
> ([README.md](../README.md)). This plan is the first-pass validation to remove that caveat.

---

## 1. Scope & candidate devices

- **Candidate devices (need 1.4.0 → 1.5.0):** `0004`, `0006`, `0008`.
- **Use exactly one device for first execution** — the one that is **physically on the
  bench with SWD/J-Link access** (an nRF5340 DK, or a Tempo-BT board with a debug
  connector). Because the build is **overwrite-only (no rollback)**, a failed net-core
  update can leave the device unreachable over BLE; SWD is the only recovery.
- The other two devices are **not** touched until this device passes all acceptance
  criteria and the recovery procedure has been rehearsed at least once.

Out of scope: production over-the-air rollout to many devices, unattended DFU, DFU
driven from the `tempo-tb-ingest` daemon (that is a later step that will reuse the
findings here).

---

## 2. What the firmware actually implements (verified from config)

| Fact | Source |
|---|---|
| Bootloader is MCUboot via sysbuild | `sysbuild.conf` |
| **Two** updateable images: app core (0) + network core (1) | `sysbuild.conf` `SB_CONFIG_MCUBOOT_UPDATEABLE_IMAGES=2`, `SB_CONFIG_NETCORE_APP_UPDATE=y` |
| **Simultaneous** multi-image update (both cores, one reboot) | `SB_CONFIG_MCUBOOT_NRF53_MULTI_IMAGE_UPDATE=y` |
| **Overwrite-only** swap mode → **no test/confirm revert** | `SB_CONFIG_MCUBOOT_MODE_OVERWRITE_ONLY=y` |
| Images are **signed** (RSA-2048, Nordic sample key) | `prj.conf` `CONFIG_MCUBOOT_SIGNATURE_KEY_FILE=...root-rsa-2048.pem` |
| Transport is **BLE/SMP only** (no serial/USB DFU; shell off) | `prj.conf` `CONFIG_MCUMGR_TRANSPORT_BT=y`, `CONFIG_SHELL=n` |
| Image mgmt group enabled | `prj.conf` `CONFIG_MCUMGR_GRP_IMG=y`, `IMG_MANAGER`, `STREAM_FLASH` |
| Secondary/staging slots live in **external QSPI flash** (`mx25r64`) | `pm_static.yml` `mcuboot_secondary` (app), `mcuboot_secondary_1` (net) |
| Net-core image reaches the net core via **PCD SRAM** handoff on reboot | `pm_static.yml` `pcd_sram`, `mcuboot_primary_1` (ram_flash) |

**nRF5340 dual-core mechanism** (Nordic Academy, Lesson 9 — DFU for the nRF5340): the app
core cannot write net-core flash directly. In simultaneous mode the client uploads both
images; each is staged in external flash; on reboot MCUboot overwrites the app slot and
uses the PCD library to reprogram the net core from its staged image. Because it is
overwrite-only, there is no swap-back — a bad image is permanent until re-flashed.

---

## 3. Artifacts under test

Produced by the existing sysbuild build in `build/`:

| File | Role |
|---|---|
| `build/dfu_application.zip` | Multi-image DFU package (app + net core + manifest) |
| ↳ `tempo-bt-v1.signed.bin` | App-core image (manifest `image_index 0`) |
| ↳ `ipc_radio.bin` | Net-core image (manifest `image_index 1`) |
| ↳ `manifest.json` | Board/soc/index metadata consumed by Device Manager |
| `build/merged.hex` / `merged_CPUNET.hex` | **Recovery** images for SWD re-flash |

**Pre-condition to verify before starting:** confirm this build is genuinely 1.5.0.
`app.version` reads `1.5.0`, but the MCUboot image version in the manifest is `0.0.0+0`,
so the MCUboot version field cannot be used as the acceptance signal (see §7).
Record the SHA-256 of `dfu_application.zip` and both `.bin`s as the "known-good" set.

---

## 4. Tooling

Primary CLI: **`smpmgr`** (0.13.2, already on PATH) with the Tempo plugin.

```bash
export SMPMGR_PLUGIN_PATH=/home/riley/src/tempo-insights/smpmgr-extensions/plugins
# addressing uses the device BLE name, e.g. Tempo-BT-0004
```

Relevant native subcommands (verified present):
- `smpmgr --ble <name> image state-read` — list images/slots, flags (`active`, `pending`, `confirmed`)
- `smpmgr --ble <name> image upload <FILE> --slot <N>` — upload one image
- `smpmgr --ble <name> os reset` — reboot to apply

> ⚠️ **Known open question (resolve in Phase 2):** smpmgr's `image upload` exposes only
> `--slot`, not an explicit mcumgr-style `--image` number, and it does **not** ingest the
> `dfu_application.zip`. We must confirm that uploading the net-core `ipc_radio.bin` with
> the correct `--slot` value actually lands in net-core image slot 1. If smpmgr cannot
> address the net-core image, fall back to the reference client below.

Reference / fallback client: **nRF Connect Device Manager** (mobile app) or the **`mcumgr`
Go CLI** (`image upload -e -n <image_num>`), both of which consume the multi-image zip and
handle image numbering natively. Use this to (a) get a first known-good OTA success and
(b) cross-check smpmgr behavior.

Recovery tool: **`nrfutil device`** / `west flash` over J-Link using `merged.hex` +
`merged_CPUNET.hex` (the `generated_nrfutil_batch.json` recipe: program + RESET_PIN).

---

## 5. Safety & risk register

| Risk | Mitigation |
|---|---|
| Overwrite-only → no rollback; bad image bricks BLE | First device must have SWD; rehearse recovery **before** first OTA (Phase 0) |
| Net-core update breaks radio mid-update | Use **simultaneous** update (single reboot), not sequential; keep device stationary/powered |
| Wrong image → wrong slot (smpmgr `--slot` ambiguity) | Phase 2 capability check before any real upload; verify with `image state-read` |
| Interrupted upload (BLE drop, power loss) | External-flash staging means partial upload is discarded on next boot; re-upload. Confirm this is true (Phase 3 abort test, optional) |
| Sample signing key (not production) | Acceptable for this test; note as a separate production hardening item, out of scope |
| **Production logs on device** | DFU touches app/net firmware + external-flash *staging* slots only, **not** the LittleFS log partition. Still: pick a device whose logs are already harvested, or back them up first. |

---

## 6. Procedure

### Phase 0 — Recovery rehearsal (do this first, before any OTA)
0.1 Connect the candidate device via SWD/J-Link.
0.2 Read out and back up anything needed; note current firmware = 1.4.0.
0.3 Practice a full SWD recovery: flash `merged.hex` + `merged_CPUNET.hex` and confirm the
    device boots and advertises. **Do not proceed to Phase 1 until recovery works.**

### Phase 1 — Baseline capture (BLE, pre-upgrade)
1.1 `smpmgr --ble Tempo-BT-000X os echo hello` → confirms SMP over BLE is up.
1.2 `smpmgr --ble Tempo-BT-000X image state-read` → record image list, hashes, slot flags.
1.3 Capture the **version indicator** (see §7): `settings-get` output and/or the chosen
    1.5.0-specific behavior, in its 1.4.0 state.
1.4 `smpmgr --ble Tempo-BT-000X tempo session-list` and download one known session; record
    its SHA-256. (Baseline for the post-upgrade regression check.)

### Phase 2 — Tooling capability check (no commitment)
2.1 With `image state-read`, map how many image slots the device reports and which index is
    net core.
2.2 Determine the correct smpmgr invocation for **each** image. If smpmgr cannot target the
    net-core image, switch to the reference client (nRF Connect Device Manager / mcumgr)
    for the actual upload and record that smpmgr alone is insufficient for multi-image.
2.3 Decide the confirmed upload recipe and write it into the results record before Phase 3.

### Phase 3 — Upload (staging)
3.1 Upload app-core image (`tempo-bt-v1.signed.bin`, index 0) to its secondary slot.
3.2 Upload net-core image (`ipc_radio.bin`, index 1) to its secondary slot.
    *(Or: single multi-image zip upload via the reference client.)*
3.3 `image state-read` → confirm **both** staged images are present with the expected
    hashes and marked pending. Compare hashes against the §3 known-good set.

### Phase 4 — Apply
4.1 `smpmgr --ble Tempo-BT-000X os reset`.
4.2 Observe: device reboots, MCUboot overwrites app slot, PCD reprograms net core. Expect a
    longer-than-normal first boot. Device should re-advertise within a reasonable window.
4.3 If the device does **not** re-advertise → invoke Phase 0 recovery, log as a failure,
    stop.

### Phase 5 — Acceptance verification (post-upgrade)
5.1 `os echo` reconnects over BLE.
5.2 `image state-read` → active image hashes now match the 1.5.0 app image; net-core image
    updated; slot flags consistent with overwrite-only (active + confirmed).
5.3 **Version acceptance:** the §7 indicator now reports 1.5.0.
5.4 Byte-level check: the running app-image hash reported by `image state-read` equals the
    SHA-256 of the app image extracted from `dfu_application.zip`.

### Phase 6 — Regression (device still fully functional)
6.1 `tempo session-list`, `storage-info` succeed.
6.2 Re-download the Phase 1.4 session; SHA-256 **must match** the pre-upgrade value
    (proves file transfer + storage intact across DFU).
6.3 `settings-get`/`settings-set` round-trip; LED on/off; logger arm/disarm — smoke the
    tempo command surface.

---

## 7. Acceptance criteria

DFU is considered **verified** when **all** hold:

1. **[Firmware identity]** A reliable version indicator shows **1.5.0** post-upgrade where
   it showed 1.4.0 before. *(Resolve the indicator in Phase 1: the tempo plugin has no
   explicit firmware-version command, so use `settings-get` if it carries a version, or a
   documented 1.5.0-only behavior such as magnetometer/`MMC5983MA` support or the v1.5.0
   `SESSION_LIST` key format. Record which signal was used.)*
2. **[Byte integrity]** The active app-image hash from `image state-read` equals the
   SHA-256 of the app image in the known-good `dfu_application.zip`.
3. **[Net core updated]** `image state-read` shows the net-core image at index 1 updated to
   the new hash; BLE/radio fully functional after reboot.
4. **[No data loss]** A session downloaded before and after the upgrade has identical
   SHA-256 (log storage untouched).
5. **[Repeatable]** The exact confirmed command sequence is documented such that devices
   `0006` and `0008` can be upgraded by following it verbatim.

---

## 8. Rollback / recovery

There is **no OTA rollback** (overwrite-only). Recovery = SWD re-flash of
`merged.hex` + `merged_CPUNET.hex` per `build/generated_nrfutil_batch.json`
(`nrfutil device` / `west flash`). This must be proven working in Phase 0.

---

## 9. Results record

### Run 1 — device 0004, 1.4.0 → 1.5.0 — **PASS**

```
Date:        2026-07-11            Executor: riley (assisted)
Device id:   0004                  Debugger present: yes (SWD available)
BLE addr:    E9:F0:2B:A7:2D:7E     (retained across the reboot this run)

Build under test SHA-256 (file):
  dfu_application.zip:    496d1e23e7b2894853a414c5e237731a51299f75d32ca243fb2811a678dc8bfe
  tempo-bt-v1.signed.bin: 064e73c7c46f972c0664a3a4de3e3e5d5c9fb946029374d2d0794a5214fde51a
  ipc_radio.bin:          f2f4438d95fd573eaf6084e7c35299eadd6e09c736500992f795e805d916bc42

MCUboot image hashes (from image state-read — the acceptance references):
  app 1.4.0 (before):  787D372CD09DB7FDE5BDC8352F7E2725BD0358ECB31348E3D68226C00275E7A4
  app 1.5.0 (staged→running): A641F7473100881EB0E9E44F99A41919F3E77B23710C30016BF84F6A7929A4F3
  net (staged):        30C143EFB73B88E0B7AC03344D0910CAD8AF269CBA3833B047B8548B8DD2633F

Phase 0 recovery rehearsed:  not run this time (SWD recovery available as safety net)
Upload client used:          smpmgr 0.13.2 (native image/os groups; tempo plugin NOT loaded)
Post-upgrade version signal:  n/a — verified by image-hash match (settings-get version not yet in fw)
App image hash matches staged 1.5.0:  YES (running slot0 == A641F747, active+confirmed)
Net core updated / BLE ok:            YES (os echo works post-reboot; radio functional)
fs group functional post-DFU:         YES (file read-size responds; 0004 is production/no testok)
Session SHA-256 pre==post:            NOT TESTED (tempo session-list plugin didn't load; see gaps)
Overall:                              PASS

Timing (BLE, single scan adapter):
  app-core upload  (337 KB):  ~23.1 s  (~14.6 KB/s)
  net-core upload  (172 KB):  ~12.9 s  (~13.3 KB/s)
  state-write x2 + os reset:  ~few s
  reset → re-advertise:       ~11 s   (both-core overwrite + PCD net-core reprogram)
  ── full upload→reconnect wall time: ~50–55 s
```

### Confirmed CLI recipe (reusable for 0006 / 0008)

```bash
export SMPMGR_PLUGIN_PATH=/home/riley/src/tempo-insights/smpmgr-extensions/plugins  # (not needed for DFU)
DEV=<ble-addr-or-name>          # rediscover by name after any reboot; MAC may re-randomize
unzip -o build/dfu_application.zip   # → tempo-bt-v1.signed.bin, ipc_radio.bin

# 1. stage both images (non-destructive; device keeps running old fw)
smpmgr --timeout 30 --ble $DEV image upload tempo-bt-v1.signed.bin --slot 0   # app  → image 0
smpmgr --timeout 30 --ble $DEV image upload ipc_radio.bin          --slot 1   # net  → image 1
smpmgr --ble $DEV image state-read      # confirm slot1/image0 + slot1/image1 present, note hashes

# 2. commit (point of no return — overwrite-only, no rollback)
smpmgr --ble $DEV image state-write <APP_STAGED_HASH> false    # mark app pending
smpmgr --ble $DEV image state-write <NET_STAGED_HASH> false    # mark net pending
smpmgr --ble $DEV os reset

# 3. verify: rediscover by name, then
smpmgr --ble $DEV image state-read      # running slot0 hash == APP_STAGED_HASH, active+confirmed
```

Key findings:
- smpmgr's native `image upload --slot N` **does** address the nRF5340 image number:
  `--slot 0` → app core (image 0), `--slot 1` → net core (image 1). The `--slot` name is a
  misnomer for "image number." No `mcumgr`/Device Manager fallback was needed.
- **Each image must be marked pending by a state-write on its OWN hash** — the app hash
  pends the app image, the net hash pends the net image. Both are required for the
  simultaneous swap. (An early guess that one write pends both was wrong: the net image had
  been pended by a prior run.) BLE reconnects occasionally drop a request, so verify the
  pending count == 2 and retry.
- **`os reset` can silently fail to trigger the reboot.** Symptom: the device "re-advertises"
  in ~11 s but `state-read` still shows the OLD image running with the new images still
  `pending=True` — it never rebooted. A real swap takes ~30–45 s. Re-issue `os reset` (with
  visible output) until `state-read` shows the new image active and the pending images gone.
- Overwrite-only behaved as designed: after the swap the new image is directly
  `active + confirmed`; the secondary slots are consumed (no revert path).
- smpmgr also exposes a one-shot `upgrade` (upload+test+reset) — usable for **single-image**
  updates, but this dual-core case needs the two uploads staged before the single reset.

### Runs 2 & 3 — devices 0005, 0006, 1.4.0 → 1.5.0 — **PASS** (via `tools/dfu-upgrade.sh`)

Both upgraded from the same `789...`→`A641F747…` app image and verified: running app hash =
`A641F747…` active+confirmed, and each **still advertises its `Tempo-BT-nnnn` name** after
the upgrade (the explicit acceptance requirement). Upload timings matched Run 1 (~23 s app /
~10–15 s net). 0005's reset took on the first try (~36 s to swap); 0006 needed a re-issued
`os reset` (first reset silently didn't reboot), then swapped in ~41 s — this is what
motivated the reset-retry loop now built into `tools/dfu-upgrade.sh`.

### Run 4 — device 0008 — re-provisioned + **PASS**

`0008` had lost its name (advertising bare `Tempo-BT`, unprovisioned) and had to be
re-provisioned before upgrading:

```
smpmgr --plugin-path=<plugins> --ble <addr> tempo settings-set --ble-name "Tempo-BT-0008" --pcb-variant 2
smpmgr --ble <addr> os reset      # name changes require a reboot
```

Then upgraded 1.4.0 → 1.5.0 (running app = `A641F747…`), and the `Tempo-BT-0008` name +
PCB-variant 0x02 **persisted across the DFU** (settings live in NVM, separate from firmware).

### Infrastructure findings (2026-07-11)

- **`--plugin-path` must use the `=` form**: `smpmgr --plugin-path=<dir> …`. smpmgr's
  `get_plugins()` only scans argv for `--plugin-path=` (with equals) and the
  `SMPMGR_PLUGIN_PATH` env var is **not** consulted. Space-separated `--plugin-path <dir>`
  silently loads nothing → `No such command 'tempo'`. This was the entire "plugin won't
  load" problem from Runs 1–3; the plugin code is fine.
- **BLE flakiness was adapter contention, not firmware.** With the 4 transfer dongles +
  onboard controller present (5 HCI controllers, dongles reading all-zero addresses),
  bleak/BlueZ discovery and connection to a device were intermittent — the `os reset`
  "device not found" and the tool's failed re-discovery were all this. With the dongles
  unplugged (single controller) a connect probe was **6/6**. smpmgr has no adapter-select
  flag, so bleak uses the BlueZ default across contending controllers.
- **Prefer bleak connect over bluetoothctl scan.** Direct `smpmgr` operations (upload,
  state-read, reset) to a known address were reliable throughout; `bluetoothctl scan`
  discovery was the flaky layer. Devices keep their BLE MAC across reboots, so post-reset
  verification should **poll the known address directly** rather than re-scan by name.
  `tools/dfu-upgrade.sh` was updated to do exactly this.

A bare unprovisioned `Tempo-BT` (no suffix) seen alongside the fleet is correctly ignored
by harvest logic — but note it is how a name-reset device (like 0008 here) appears.

### Note: same-version OTA re-apply is not possible

`0010` was flashed to 1.5.0 over SWD/J-Link. An attempt to re-run the OTA on it (to exercise
the full swap cycle on the single-adapter setup) revealed a hard limit: **you cannot OTA the
same firmware version a device is already running.** The staged app image has the *same*
MCUboot hash as the running image, and `image state-write <hash> false` cannot distinguish
the secondary slot from the active primary — so the app image never gets marked pending
(only the net image, which has a distinct hash, did). The tool detects this (pending count
stays 1) and refuses to reset, so the device is left untouched. Consequence: OTA is for
version *changes* only; to re-flash the same version use SWD/J-Link. (A leftover net-image
pending flag from the attempt clears harmlessly on the next reboot.)

### Gaps / follow-ups
- **Tempo group-64 plugin did not load** under smpmgr 0.13.2 (`No such command 'tempo'`,
  even with `--plugin-path`). This blocked `session-list`/`settings-get` baseline and the
  byte-for-byte session download regression. Investigate plugin/smpmgr API compatibility
  separately; it does not affect the native DFU path.
- Net-core image is not directly re-readable via `image state-read` after boot (nRF5340
  limitation) — functional BLE is the proxy for net-core success.
- Repeat on `0006` and `0008` using the recipe above; consider a Phase-0 recovery rehearsal
  first on whichever unit is least accessible.

Post-run: `README.md` OTA line updated (validated); recommend also adding a line to the
`tempo-tb-ingest` `docs/feasibility.md` validation history.

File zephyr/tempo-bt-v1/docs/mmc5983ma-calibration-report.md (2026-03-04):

# MMC5983MA Magnetometer Calibration for Tempo-BT AHRS Integration

## Research Report — February 2026

---

## 1. Context and Objectives

The Tempo-BT skydiving logger includes a MEMSIC MMC5983MA 3-axis magnetic sensor (currently unused) alongside a TDK ICM-42688-V 6-DOF IMU. Integrating the magnetometer into a Madgwick Fusion AHRS algorithm would upgrade the system from 6-DOF (gyro + accelerometer) to 9-DOF (MARG: Magnetic, Angular Rate, Gravity), providing absolute heading reference — particularly valuable for reconstructing skydive trajectories and body orientation.

Achieving accurate heading from the magnetometer requires addressing multiple layers of calibration and compensation. This report identifies what's needed and assesses implementation options.

---

## 2. What the MMC5983MA Brings to the Table

Key sensor specifications relevant to AHRS integration:

| Parameter | Value |
|---|---|
| Field Range | ±8 Gauss per axis |
| Resolution (18-bit) | 0.0625 mG/LSB (16384 counts/G) |
| Total RMS Noise (BW=00) | 0.4 mG |
| Max Output Rate (BW=11, CM) | 1000 Hz |
| Heading Accuracy (claimed) | ±1.0° typical |
| Null Field Output (18-bit) | 131072 counts (unsigned midpoint) |
| I²C Address | 0x30 (7-bit: 0110000) |
| Operating Temp | -40°C to +105°C |

The MMC5983MA uses unsigned output format — the midpoint (131072 at 18-bit) represents zero field. Earth's magnetic field is roughly 250–650 mG depending on location, so the sensor has substantial headroom.

**Notable hardware feature:** The built-in SET/RESET coil is critical for this sensor. It provides on-chip degaussing that eliminates thermal drift of the null-field offset — a significant advantage over competitors lacking this capability.

---

## 3. Calibration Layers Required

Integrating the MMC5983MA into the Madgwick AHRS requires addressing calibration at multiple levels. These are distinct concerns that build on each other:

### Layer 1: Sensor-Level — SET/RESET Bridge Offset Elimination

The MMC5983MA's AMR sensing elements have an inherent bridge offset that drifts with temperature. The datasheet prescribes a SET/RESET measurement protocol to eliminate this:

1. Perform **SET** (write 0x08 to Control Register 0) — magnetizes sensing film in one direction
2. Take measurement → `Output_SET = +H + Offset`
3. Perform **RESET** (write 0x10 to Control Register 0) — magnetizes film in opposite direction
4. Take measurement → `Output_RESET = -H + Offset`
5. Compute: `H = (Output_SET - Output_RESET) / 2` and `Offset = (Output_SET + Output_RESET) / 2`

This eliminates the temperature-dependent bridge offset entirely. The `Auto_SR_en` bit in Control Register 0 can automate this, but explicit control gives better results. The sensor can also perform periodic SET operations in continuous measurement mode via `En_prd_set` and `Prd_set[2:0]`.

**Important soldering caution:** The DRNadler/MMC5983MA_CompassTest project on GitHub documents that overheating during soldering can permanently damage the sensor's AMR film, causing the SET/RESET procedure to fail to properly auto-zero. Verify sensor health with a field-magnitude consistency test after board assembly.

**Firmware requirement:** The Zephyr driver or custom driver code must implement the SET/RESET measurement protocol. This is not optional — without it, the raw readings will have temperature-dependent offsets of up to ±0.5 G, which is comparable to or larger than Earth's field components.

### Layer 2: Hard and Soft Iron Calibration (HSI)

Even with perfect sensor-level operation, the magnetometer will measure a distorted version of Earth's field due to magnetic materials on or near the PCB:

- **Hard iron distortions** are constant magnetic fields from permanently magnetized materials (battery, speaker magnets, magnetized steel). They create a fixed bias — shifting the measurement sphere away from the origin.

- **Soft iron distortions** are caused by ferromagnetic materials (nickel, iron) that warp the existing field. They distort the measurement sphere into an ellipsoid.

As described by VectorNav's educational material, the compensation model is:

```
m_corrected = S_I × (m_raw - b_HI)
```

Where `S_I` is a 3×3 soft iron correction matrix and `b_HI` is a 3-element hard iron bias vector. Together these 12 parameters map the distorted ellipsoid back to a sphere centered at the origin.

**For the Tempo-BT specifically:** The PCB has a LiPo battery, a u-blox SAM-M10Q GNSS module, and other components that will create both hard and soft iron distortions. These must be characterized with the device fully assembled in its enclosure with battery connected.

### Layer 3: Sensor Alignment / Cross-Axis Calibration

The MMC5983MA has a specified alignment error of ±1.0° typical (±3.0° max) between its sensing axes and the package. For AHRS integration, the magnetometer's coordinate frame must be aligned with the ICM-42688-V accelerometer/gyro coordinate frame. Misalignment between the two sensors contributes directly to heading error.

This can be folded into the soft iron matrix or handled as a separate rotation matrix.

#### Tempo-BT sensor package mounting alignment

The sensor packages are placed on the PCB such that sensor axis coordinate frames are aligned in this manner:

| ICM-42688-V Axis | MMC5983MA Axis |
|:---:|:---:|
| +X | -Y |
| +Y | +X |
| +Z | -Z |

### Layer 4: Madgwick Filter Integration

The Madgwick AHRS filter's `updateMARG()` function expects calibrated, normalized magnetometer data in the same coordinate frame as the accelerometer and gyroscope. Key requirements:

- Magnetometer readings must be calibrated (hard/soft iron corrected) before being passed to the filter
- The magnetometer coordinate frame must be aligned with the IMU frame
- The filter's `beta` parameter controls how much weight is given to the magnetometer/accelerometer correction vs. gyro integration — this needs tuning for the skydiving use case

---

## 4. Calibration Data Collection Procedure

The standard approach for HSI calibration requires collecting magnetometer samples while slowly rotating the device through all orientations:

**For 2D calibration** (heading only, device stays approximately level): Rotate the device in a few 360° circles about the gravity vector. Sufficient if pitch/roll stays within ±5-10°.

**For full 3D calibration** (recommended for skydiving AHRS): Slowly tumble the device through as many orientations as possible, aiming to uniformly cover the surface of a sphere. This typically requires 30-60 seconds of deliberate rotation, collecting hundreds to thousands of samples.

For the Tempo-BT, the recommended procedure is:

1. Power on the device with firmware in a "calibration data collection" mode
2. Stream raw (SET/RESET-corrected) magnetometer data via BLE or USB serial
3. Slowly tumble the device through all orientations outdoors, away from large metal structures
4. Capture the data on a desktop computer for offline processing

---

## 5. Calibration Algorithm Options

### 5A: Ellipsoid Fitting (Recommended)

The gold standard for magnetometer HSI calibration. The algorithm fits the collected 3D data points to an ellipsoid, then computes the transformation that maps the ellipsoid back to a unit sphere centered at the origin.

The mathematical foundation: raw magnetometer data in the absence of time-varying distortions traces an ellipsoid in 3D space. The ellipsoid's center gives the hard iron offset; its shape (axes lengths and rotation) encodes the soft iron distortion.

**Algorithmic approaches:**

| Method | Complexity | Quality | Notes |
|---|---|---|---|
| Least-squares ellipsoid fit (Li et al.) | Low | Good | Single-step, easy to implement |
| Levenberg-Marquardt iterative fit | Medium | Better | Two-stage: sphere fit → ellipsoid refinement |
| Min/max per axis (simple) | Trivial | Poor | Only corrects hard iron, ignores soft iron |

The least-squares approach is well-suited for a desktop calibration tool. The key reference implementation is Yury Petrov's `ellipsoid_fit` (MATLAB), which has been ported to Python by several authors.

### 5B: Existing Open-Source Implementations

| Project | Language | Notes |
|---|---|---|
| [nliaudat/magnetometer_calibration](https://github.com/nliaudat/magnetometer_calibration) | Python (numpy) | CSV/TXT input, 3D visualization, exports C header constants. Well-maintained. |
| [lundeen06/magnetometer-calibration-tool](https://github.com/lundeen06/magnetometer-calibration-tool) | Python (CLI) | Full CLI tool with serial port monitoring, real-time plotting, auto-generates C header. Originally for Stanford satellite. |
| [jremington/AltIMU-AHRS](https://github.com/jremington/AltIMU-AHRS) | Arduino + Python | Includes both Madgwick and Mahony AHRS implementations plus Python calibration script. Direct reference for your use case. |
| [kriswiner/MMC5983MA](https://github.com/kriswiner/MMC5983MA) | Arduino/C++ | Complete MMC5983MA driver with SET/RESET, self-test, and min/max calibration. 10-DOF AHRS sketch. |
| [DRNadler/MMC5983MA_CompassTest](https://github.com/DRNadler/MMC5983MA_CompassTest) | C++ / wxWidgets | Desktop test app specifically for MMC5983MA. Documents soldering damage issues. |
| [Teslabs magnetometer calibration](https://teslabs.com/articles/magnetometer-calibration/) | Python | Excellent tutorial with mathematical derivation and Raspberry Pi example. |
| [michal34512/Magnetometer-calibration](https://github.com/michal34512/Magnetometer-calibration) | C | Lightweight C library with built-in linear algebra — could run on-device. |
| ST DT0059 Design Tip | MATLAB/C | STMicroelectronics reference for ellipsoid fitting. Covers rotated ellipsoid case. |

---

## 6. Recommended Implementation Architecture

Given your preference for custom desktop-based tooling, here is a recommended architecture:

### Component 1: Firmware — MMC5983MA Driver + Calibration Data Streaming

**Platform:** Zephyr RTOS on nRF5340 (existing Tempo-BT firmware)

Responsibilities:
- Full MMC5983MA driver implementing SET/RESET measurement protocol
- Self-test verification (uses St_enp/St_enm bits to verify sensor health)
- Raw data streaming mode over BLE (or USB CDC if available) for calibration
- Runtime application of calibration parameters (stored in flash/NVS)
- Calibrated data output to Madgwick AHRS filter

Key driver considerations:
- Use 18-bit mode for maximum resolution during calibration
- Implement the full SET/RESET per-measurement cycle for offset elimination
- Use BW=00 (8ms measurement, 0.4mG noise) during calibration collection
- Store calibration parameters (3 hard iron offsets + 9 soft iron matrix elements = 12 floats) in non-volatile storage

### Component 2: Desktop Calibration Tool

**Recommended stack:** Python with numpy, scipy, matplotlib

This is where you'd develop custom tooling. A desktop application that:

1. **Connects** to the Tempo-BT via BLE or serial to receive raw magnetometer data
2. **Visualizes** incoming data in real-time as a 3D scatter plot, showing coverage of the measurement sphere
3. **Guides** the user through the calibration rotation procedure with visual feedback on coverage quality
4. **Computes** the ellipsoid fit once sufficient data is collected, producing hard iron (3-vector) and soft iron (3×3 matrix) parameters
5. **Validates** the calibration by displaying corrected data as a sphere, reporting field magnitude consistency
6. **Exports** calibration parameters in a format the firmware can consume (C header, JSON, binary blob for NVS)

**Coverage quality metric:** A good calibration requires data points distributed across the full sphere. The tool should assess angular coverage and warn if large gaps exist.

**Recommended Python libraries:**
- `numpy` / `scipy` — ellipsoid fitting via least-squares
- `matplotlib` — 3D scatter plots for visualization
- `bleak` — BLE communication with the Tempo-BT
- `pyserial` — alternative serial communication
- `pyqt6` or `tkinter` — GUI framework if desired (matplotlib alone can serve for a simpler tool)

### Component 3: Validation / Verification Harness

After calibration, verify the results:

- **Field magnitude consistency test:** Rotate the calibrated device; `sqrt(x² + y² + z²)` should remain approximately constant (matching the local geomagnetic field strength from the World Magnetic Model for your location, typically 450-600 mG in the US).
- **Heading comparison:** Compare computed heading against a known reference direction.
- **AHRS convergence test:** Feed calibrated magnetometer data plus IMU data through the Madgwick filter and verify heading stability and convergence time.

### Component 4: Madgwick AHRS Integration

Modify the existing Tempo-BT firmware to:

1. Initialize the Madgwick filter in MARG (9-DOF) mode instead of IMU-only (6-DOF) mode
2. On each sensor fusion cycle:
   - Read accelerometer + gyro from ICM-42688-V (existing)
   - Read magnetometer from MMC5983MA (new)
   - Apply SET/RESET correction to mag data
   - Apply HSI calibration: `m_cal = S_I × (m_raw - b_HI)`
   - Transform mag data to IMU coordinate frame
   - Call `MadgwickAHRSupdate(gx, gy, gz, ax, ay, az, mx, my, mz)`
3. Tune the `beta` parameter for the skydiving use case (higher beta = faster convergence but more noise sensitivity; lower beta = smoother but slower to track heading changes)

---

## 7. Implementation Approach Options

### Option A: Minimal / Fastest Path

Use the `kriswiner/MMC5983MA` Arduino driver as reference for the Zephyr driver, implement min/max calibration (hard iron only) on-device, and use the `jremington/AltIMU-AHRS` Python script for offline soft iron calibration.

**Pros:** Fastest to working prototype. Leverages battle-tested code.
**Cons:** Min/max calibration is limited; less accurate soft iron correction.

### Option B: Custom Desktop Tool (Recommended)

Develop a Python desktop tool that handles data collection, full 3D ellipsoid fitting, visualization, and parameter export. Use the `nliaudat/magnetometer_calibration` or `teslabs` implementations as starting points for the ellipsoid fitting math.

**Pros:** Full control over the calibration process, best accuracy, reusable for production calibration of multiple devices, visual feedback improves calibration quality.
**Cons:** More development effort up front.

### Option C: Full Integrated Solution

Option B plus: real-time 3D visualization during data collection, automated coverage analysis, on-device calibration verification mode, and a BLE-based calibration workflow (potentially via a mobile companion app).

**Pros:** Best user experience, suitable for end-user recalibration.
**Cons:** Significant development effort; may be overkill for initial integration.

---

## 8. Risk Areas and Mitigations

| Risk | Impact | Mitigation |
|---|---|---|
| Sensor damage from soldering | High — sensor may be permanently impaired | Verify with field magnitude test post-assembly; follow MEMSIC reflow profile strictly (260°C max, 10s) |
| LiPo battery magnetization | Medium — hard iron source that may vary with charge state | Characterize with battery at different charge levels; recalibrate if needed |
| Time-varying distortions during skydive | Medium — nearby magnets from other gear, aircraft | The Madgwick filter has built-in magnetic distortion rejection; consider weighting mag contribution lower during high-dynamic phases |
| Coordinate frame alignment between MMC5983MA and ICM-42688-V | Medium — directly affects heading accuracy | Measure or compute rotation matrix between sensor frames from PCB layout |
| Temperature effects during skydive (ground ~30°C to altitude ~-20°C) | Low-Medium — SET/RESET handles null offset drift | Use periodic SET/RESET; MMC5983MA spec shows ±3 mG drift with SET/RESET over full temp range |

---

## 9. Recommended Next Steps

1. **Enable the MMC5983MA driver in Zephyr firmware** — implement SET/RESET measurement protocol; verify sensor health with self-test
2. **Add a raw data streaming mode** — BLE characteristic or USB serial output of SET/RESET-corrected magnetometer data
3. **Build the desktop calibration tool** (Python) — start with the ellipsoid fitting math from existing open-source, add 3D visualization and parameter export
4. **Perform initial calibration** of a Tempo-BT unit in its enclosure with battery
5. **Integrate calibrated mag data into Madgwick AHRS** — upgrade from 6-DOF to 9-DOF
6. **Tune and validate** — compare AHRS heading output against known references, tune beta parameter

---

## 10. MCUmgr Integration — Calibration and Settings Protocol

The Tempo-BT firmware exposes magnetometer calibration and settings via custom mcumgr SMP commands over BLE. All commands use **group ID 64** (`MGMT_GROUP_ID_TEMPO`). The request/response payload is CBOR-encoded.

The mcumgr SMP protocol runs over BLE using the standard SMP service UUID. Clients can use the `mcumgr` CLI tool, the nRF Connect mobile app (with custom group support), or any SMP-capable library (e.g., `smpclient` for Python, `mcumgr-android`, `mcumgr-ios`).

### 10.1 Magnetometer Mode Setting

The `mag_mode` setting controls how the magnetometer is used in the AHRS pipeline. It is stored in NVM and persists across reboots.

| Mode | Behavior |
|:----:|---|
| 0 | **Disabled** (default). Magnetometer is not used in AHRS. No `$PMAG` sentences in log output. AHRS runs as 6-DOF (gyro + accel only). |
| 1 | **Factory calibration**. Magnetometer enabled for 9-DOF AHRS using only the factory/devicetree calibration values. Any NVM calibration is cleared on boot. |
| 2 | **NVM calibration**. Magnetometer enabled for 9-DOF AHRS using calibration data stored in NVM (pushed via `MAG_CAL_SET`). |

The mode is read and written as part of the general settings commands (IDs 6 and 7). A device reboot is required for mode changes to take effect.

### 10.2 Settings Get — Command ID 6 (READ)

Returns all device settings including `mag_mode`.

**Request:** Empty (no payload required).

**Response (CBOR map):**
```json
{
    "ble_name": "Tempo-BT",
    "pps_enabled": false,
    "pcb_variant": 1,
    "log_backend": "littlefs",
    "mag_mode": 0
}
```

| Field | Type | Description |
|---|---|---|
| `ble_name` | string | BLE advertising name (max 31 chars) |
| `pps_enabled` | bool | PPS sync enabled (always false on V1) |
| `pcb_variant` | uint | PCB revision (0x01 = V1) |
| `log_backend` | string | `"littlefs"` or `"fatfs"` |
| `mag_mode` | uint | Magnetometer mode (0/1/2) |

### 10.3 Settings Set — Command ID 7 (WRITE)

Sets one or more device settings. Only include the fields you want to change.

**Request (CBOR map) — any subset of fields:**
```json
{
    "mag_mode": 2
}
```

**Response:** Returns all current settings (same format as Settings Get) plus `"success": true`. If `ble_name` was changed, includes `"note": "BLE name changes require reboot"`.

### 10.4 Mag Calibration Get — Command ID 10 (READ)

Returns the current magnetometer calibration data from the running firmware. This reflects whatever calibration is currently active in memory (may differ from NVM if mode 1 cleared it on boot).

**Request:** Empty (no payload required).

**Response (CBOR map):**
```json
{
    "valid": true,
    "offset_x": 960,
    "offset_y": -6440,
    "offset_z": -1257,
    "scale_x": 36863,
    "scale_y": 35809,
    "scale_z": 27398
}
```

| Field | Type | Description |
|---|---|---|
| `valid` | bool | `true` if calibration data has been loaded/set |
| `offset_x` | int32 | Hard-iron X offset in raw counts (16384 counts/Gauss) |
| `offset_y` | int32 | Hard-iron Y offset in raw counts |
| `offset_z` | int32 | Hard-iron Z offset in raw counts |
| `scale_x` | uint16 | Soft-iron X scale factor (Q1.15 fixed-point; 32768 = 1.0) |
| `scale_y` | uint16 | Soft-iron Y scale factor (Q1.15 fixed-point) |
| `scale_z` | uint16 | Soft-iron Z scale factor (Q1.15 fixed-point) |

**Interpreting offset values:** The offsets represent the center of the measurement ellipsoid in the magnetometer's native coordinate frame. These are subtracted from raw readings before scale correction.

**Interpreting scale values:** The scale factors are diagonal elements of the soft-iron correction matrix in Q1.15 fixed-point format. A value of 32768 means no correction (1.0x). Values above 32768 expand the axis; values below compress it. The correction normalizes the ellipsoid radii to a sphere.

To convert from the `mag_cal.py` JSON output:
- `offset_x/y/z`: Use directly (integer counts)
- `scale_x/y/z`: Use directly (already in Q1.15 format as computed by `mag_cal.py`)
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

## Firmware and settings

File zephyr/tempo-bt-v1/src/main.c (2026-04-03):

/*
 * SPDX-License-Identifier: Apache-2.0
 * 
 * Tempo-BT V1 - Main Application Entry
 */

#include <zephyr/kernel.h>
#include <zephyr/logging/log.h>
#include <zephyr/drivers/uart.h>
#include <zephyr/device.h>
#include <zephyr/drivers/flash.h>
#include <zephyr/drivers/gpio.h>
#include <zephyr/fs/fs.h>
#include <string.h>

#include "app_init.h"
#include "app/events.h"
#include "config/settings.h"

#include "services/timebase.h"
#include "services/storage.h"
#include "services/file_writer.h"
#include "services/gnss.h"
#include "services/imu.h"
#include "services/baro.h"
#include "services/logger.h"
#include "services/led.h"
#include "services/aggregator.h"
#include "services/orientation.h"
#if CONFIG_MMC5983MA
#include "services/mag.h"
#endif
#include "util/nmea_checksum.h"
#include "app/log_format.h"
#ifdef CONFIG_USB_TTY_OUTPUT
#include "services/usb_tty.h"
#include "services/usb_cmd.h"
#include "ble_mcumgr.h"
#endif

LOG_MODULE_REGISTER(main, LOG_LEVEL_INF);

 /* Register barometer callback with logger for takeoff detection */
//extern void logger_register_baro_callback(baro_data_callback_t callback);
//extern void logger_baro_handler(const baro_sample_t *sample);

/* Also register with aggregator for logging */
extern void aggregator_register_baro_callback(baro_data_callback_t callback);

/*
 * Button handling for logger control
 */

#define BUTTON_DEBOUNCE_DELAY_MS 50
#define BUTTON_LONG_PRESS_MS     2000

/* Button GPIO specs from device tree */
#define SW0_NODE DT_ALIAS(sw0)
#define SW1_NODE DT_ALIAS(sw1)

#define LED0_NODE DT_ALIAS(led1)
static const struct gpio_dt_spec led = GPIO_DT_SPEC_GET(LED0_NODE, gpios);

#if DT_NODE_HAS_STATUS(SW0_NODE, okay)
static const struct gpio_dt_spec button0 = GPIO_DT_SPEC_GET(SW0_NODE, gpios);
static struct gpio_callback button0_cb_data;
static struct k_work_delayable button0_work;
static struct k_work button0_action_work;  /* For logger start/stop (can't run in ISR) */
static int64_t button0_press_time;
static bool button0_pending_start;  /* true = start, false = stop */

/*
 * Dedicated work queue for button actions that call logger_start/stop.
 * The system work queue stack (2KB) is too small for FAT filesystem I/O.
 */
#define BUTTON_WQ_STACK_SIZE 3072
#define BUTTON_WQ_PRIORITY   5
static K_THREAD_STACK_DEFINE(button_wq_stack, BUTTON_WQ_STACK_SIZE);
static struct k_work_q button_workq;
#endif

#if DT_NODE_HAS_STATUS(SW1_NODE, okay)
static const struct gpio_dt_spec button1 = GPIO_DT_SPEC_GET(SW1_NODE, gpios);
static struct gpio_callback button1_cb_data;
static struct k_work_delayable button1_work;
static struct k_work button1_action_work;
static int64_t button1_press_time;
#endif

/* Forward declaration for LED state update */
static void update_led_for_state(logger_state_t state);

/* Magnetometer calibration streaming state */
#if CONFIG_MMC5983MA && defined(CONFIG_USB_TTY_OUTPUT)
static volatile bool mag_cal_streaming;
static struct k_work button1_short_press_work;
static struct k_work_delayable mag_cal_stream_work;

#define MAG_CAL_STREAM_PERIOD_MS  50  /* 20 Hz raw mag output */

static void mag_cal_stream_handler(struct k_work *work)
{
    ARG_UNUSED(work);

    if (!mag_cal_streaming) {
        return;
    }

    int32_t raw_x, raw_y, raw_z;
    float temp_c;
    int ret = mag_read_raw_counts(&raw_x, &raw_y, &raw_z, &temp_c);

    if (ret == 0) {
        char line[LOG_MAX_SENTENCE_LEN];
        uint32_t timestamp_ms = (uint32_t)(k_uptime_get() & 0xFFFFFFFF);
        int len = log_format_sentence(line, sizeof(line),
                                      "$PRMG,%u,%d,%d,%d,%.1f",
                                      timestamp_ms,
                                      raw_x, raw_y, raw_z, (double)temp_c);
        if (len > 0) {
            usb_tty_output_line(line, len);
        }
    }

    k_work_reschedule(&mag_cal_stream_work, K_MSEC(MAG_CAL_STREAM_PERIOD_MS));
}

/*
 * USB disconnect handler for mag calibration mode.
 * Called from system workqueue when the host closes the serial port.
 */
static void mag_cal_disconnect_handler(void)
{
    if (mag_cal_streaming) {
        mag_cal_streaming = false;
        k_work_cancel_delayable(&mag_cal_stream_work);
        usb_cmd_set_active(false);
        usb_tty_close();
        ble_mcumgr_restart();
        update_led_for_state(logger_get_state());
        LOG_INF("Mag cal stopped (USB disconnect)");
    }
}

static void button1_short_press_handler(struct k_work *work)
{
    ARG_UNUSED(work);

    if (mag_cal_streaming) {
        /* Stop calibration streaming */
        mag_cal_streaming = false;
        k_work_cancel_delayable(&mag_cal_stream_work);
        usb_cmd_set_active(false);
        usb_tty_close();
        LOG_INF("Mag calibration streaming stopped");
        ble_mcumgr_restart();
        update_led_for_state(logger_get_state());
    } else {
        /* Start calibration streaming */
        if (!mag_is_ready()) {
            LOG_WRN("Magnetometer not ready for calibration");
            return;
        }
        int ret = usb_tty_open();
        if (ret == -ENOTCONN) {
            LOG_INF("BTN1 short: no USB host connected, ignoring");
            return;
        }
        mag_cal_streaming = true;
        usb_cmd_set_active(true);
        usb_tty_register_disconnect_callback(mag_cal_disconnect_handler);
        LOG_INF("Mag calibration streaming started (20 Hz $PRMG + commands)");
        ble_mcumgr_stop();
        set_color_led_state(RGB_MAGENTA, true);
        k_work_schedule(&mag_cal_stream_work, K_NO_WAIT);
    }
}
#endif /* CONFIG_MMC5983MA && CONFIG_USB_TTY_OUTPUT */

/* Button work handler for long press detection */
static void button0_work_handler(struct k_work *work)
{
    ARG_UNUSED(work);

    /* Check if button is still pressed */
    int val = gpio_pin_get_dt(&button0);
    if (val == 1) { /* Active low, so 1 means pressed */
        int64_t press_duration = k_uptime_get() - button0_press_time;

        if (press_duration >= BUTTON_LONG_PRESS_MS) {
            LOG_INF("Button 0 long press detected");

            /* Long press: manually start logging when armed
             * This is a safety feature - requires deliberate action to start logging */
            logger_state_t state = logger_get_state();
            if (state == LOGGER_STATE_ARMED) {
                button0_pending_start = true;
                k_work_submit_to_queue(&button_workq, &button0_action_work);
            }
        }
    }
}

/* Button action work handler - runs logger start/stop outside ISR context */
static void button0_action_handler(struct k_work *work)
{
    ARG_UNUSED(work);

    if (button0_pending_start) {
        int ret = logger_start("manual_start");
        if (ret == 0) {
            /* Update LED to reflect new logging state */
            update_led_for_state(logger_get_state());
        }
    } else {
        logger_stop();
    }
}

/* Button interrupt callbacks */
static void button0_pressed(const struct device *dev, struct gpio_callback *cb,
                            uint32_t pins)
{
    ARG_UNUSED(dev);
    ARG_UNUSED(cb);
    ARG_UNUSED(pins);
    
    button0_press_time = k_uptime_get();
    
    /* Schedule work to check for long press */
    k_work_reschedule(&button0_work, K_MSEC(BUTTON_LONG_PRESS_MS));
}

static void button0_released(const struct device *dev, struct gpio_callback *cb,
                             uint32_t pins)
{
    ARG_UNUSED(dev);
    ARG_UNUSED(cb);
    ARG_UNUSED(pins);

    /* Cancel long press detection */
    k_work_cancel_delayable(&button0_work);

    int64_t press_duration = k_uptime_get() - button0_press_time;

    if (press_duration < BUTTON_LONG_PRESS_MS &&
        press_duration > BUTTON_DEBOUNCE_DELAY_MS) {
        /* Short press: no effect (safety feature)
         * Only long press can start logging to prevent accidental activation */
        LOG_DBG("Button 0 short press - ignored");
    }
}

#if DT_NODE_HAS_STATUS(SW1_NODE, okay)
/* Button 1 long press detection — mirrors button 0 pattern */
static void button1_work_handler(struct k_work *work)
{
    ARG_UNUSED(work);

    int val = gpio_pin_get_dt(&button1);
    if (val == 1) {
        int64_t press_duration = k_uptime_get() - button1_press_time;

        if (press_duration >= BUTTON_LONG_PRESS_MS) {
            LOG_INF("Button 1 long press detected");
            k_work_submit_to_queue(&button_workq, &button1_action_work);
        }
    }
}

/* Button 1 (BTN2) action — runs outside ISR context */
static void button1_action_handler(struct k_work *work)
{
    ARG_UNUSED(work);

#ifdef CONFIG_USB_TTY_OUTPUT
    logger_state_t state = logger_get_state();

    if (state == LOGGER_STATE_LOGGING || state == LOGGER_STATE_JUMPED) {
        /* Stop current session (works for both USB and SD modes) */
        logger_stop();
        update_led_for_state(logger_get_state());
    } else if (state == LOGGER_STATE_IDLE || state == LOGGER_STATE_ARMED) {
        int ret = logger_start_usb();
        if (ret == -ENOTCONN) {
            LOG_INF("BTN1: no USB host connected, ignoring");
        } else if (ret == 0) {
            update_led_for_state(logger_get_state());
        } else {
            LOG_WRN("BTN1: USB logging start failed: %d", ret);
        }
    }
#else
    LOG_INF("Button 1 pressed (USB TTY not enabled)");
#endif
}

static void button1_isr(const struct device *dev, struct gpio_callback *cb,
                        uint32_t pins)
{
    ARG_UNUSED(dev);
    ARG_UNUSED(cb);
    ARG_UNUSED(pins);

    int val = gpio_pin_get_dt(&button1);
    if (val == 1) {
        /* Pressed */
        button1_press_time = k_uptime_get();
        k_work_reschedule(&button1_work, K_MSEC(BUTTON_LONG_PRESS_MS));
    } else {
        /* Released — cancel long press detection */
        k_work_cancel_delayable(&button1_work);

        /* Detect short press for mag calibration toggle */
        int64_t press_duration = k_uptime_get() - button1_press_time;
        if (press_duration < BUTTON_LONG_PRESS_MS &&
            press_duration > BUTTON_DEBOUNCE_DELAY_MS) {
#if CONFIG_MMC5983MA && defined(CONFIG_USB_TTY_OUTPUT)
            /* Short press: toggle mag calibration streaming
             * (only when not actively logging) */
            logger_state_t state = logger_get_state();
            if (mag_cal_streaming ||
                state == LOGGER_STATE_IDLE ||
                state == LOGGER_STATE_ARMED) {
                k_work_submit_to_queue(&button_workq, &button1_short_press_work);
            }
#endif
        }
    }
}
#endif

static void button0_isr(const struct device *dev, struct gpio_callback *cb, uint32_t pins)
{
    ARG_UNUSED(dev);
    ARG_UNUSED(cb);
    ARG_UNUSED(pins);

    int val = gpio_pin_get_dt(&button0);
    if (val == 1) { /* Pressed (active low) */
        button0_pressed(dev, cb, pins);
    } else {
        button0_released(dev, cb, pins);
    }
}

/* Initialize button handling */
int buttons_init(void)
{
    int ret;
    
#if DT_NODE_HAS_STATUS(SW0_NODE, okay)
    if (!device_is_ready(button0.port)) {
        LOG_ERR("Button 0 device not ready");
        return -ENODEV;
    }
    
    ret = gpio_pin_configure_dt(&button0, GPIO_INPUT);
    if (ret != 0) {
        LOG_ERR("Failed to configure button 0: %d", ret);
        return ret;
    }
    
    ret = gpio_pin_interrupt_configure_dt(&button0, GPIO_INT_EDGE_BOTH);
    if (ret != 0) {
        LOG_ERR("Failed to configure button 0 interrupt: %d", ret);
        return ret;
    }
    
    k_work_init_delayable(&button0_work, button0_work_handler);
    k_work_init(&button0_action_work, button0_action_handler);

    /* Start dedicated work queue for button actions (needs larger stack for FAT I/O) */
    k_work_queue_init(&button_workq);
    k_work_queue_start(&button_workq, button_wq_stack,
                       K_THREAD_STACK_SIZEOF(button_wq_stack),
                       BUTTON_WQ_PRIORITY, NULL);

    gpio_init_callback(&button0_cb_data,
                       button0_isr,
                       BIT(button0.pin));
    
    gpio_add_callback(button0.port, &button0_cb_data);
    
#endif

#if DT_NODE_HAS_STATUS(SW1_NODE, okay)
    if (!device_is_ready(button1.port)) {
        LOG_ERR("Button 1 device not ready");
        return -ENODEV;
    }
    
    ret = gpio_pin_configure_dt(&button1, GPIO_INPUT);
    if (ret != 0) {
        LOG_ERR("Failed to configure button 1: %d", ret);
        return ret;
    }
    
    ret = gpio_pin_interrupt_configure_dt(&button1, GPIO_INT_EDGE_BOTH);
    if (ret != 0) {
        LOG_ERR("Failed to configure button 1 interrupt: %d", ret);
        return ret;
    }

    k_work_init_delayable(&button1_work, button1_work_handler);
    k_work_init(&button1_action_work, button1_action_handler);
#if CONFIG_MMC5983MA && defined(CONFIG_USB_TTY_OUTPUT)
    k_work_init(&button1_short_press_work, button1_short_press_handler);
    k_work_init_delayable(&mag_cal_stream_work, mag_cal_stream_handler);
#endif

    gpio_init_callback(&button1_cb_data, button1_isr, BIT(button1.pin));
    gpio_add_callback(button1.port, &button1_cb_data);
    
#endif

    return 0;
}

/* State change handler */
static void update_led_for_state(logger_state_t state)
{
    switch (state) {
    case LOGGER_STATE_IDLE:
        /* Blue slow blink for idle */
        set_color_led_state(RGB_BLUE, true);
        LOG_INF("LED: Blue (idle)");
        break;

    case LOGGER_STATE_ARMED:
        /* No blink for armed */
        set_color_led_state(RGB_BLACK, true);
        LOG_INF("LED: Off (armed)");
        break;

    case LOGGER_STATE_LOGGING:
        /* Green slow blink for logging (climbing) */
        set_color_led_state(RGB_GREEN, true);
        LOG_INF("LED: Green (logging)");
        break;

    case LOGGER_STATE_JUMPED:
        /* Orange slow blink for active jump (freefall/canopy) */
        set_color_led_state(RGB_ORANGE, true);
        LOG_INF("LED: Orange (jumped)");
        break;

    case LOGGER_STATE_ERROR:
    default:
        /* Red slow blink for error */
        set_color_led_state(RGB_RED, true);
        LOG_INF("LED: Red (error)");
        break;
    }
}

/* Event handler for state changes */
static void led_event_handler(const app_event_t *event, void *user_data)
{
    ARG_UNUSED(user_data);
    
    switch (event->type) {
    case EVT_STATE_CHANGE:
        /* Update LED based on logger state */
        update_led_for_state(logger_get_state());
        break;
        
    case EVT_STORAGE_ERROR:
    case EVT_SENSOR_ERROR:
        /* Flash red for errors */
        set_color_led_state(RGB_RED, true);
        break;
        
    case EVT_STORAGE_LOW:
        /* Could flash yellow as warning */
        break;
        
    default:
        break;
    }
}


/* Event subscriber for LED */
static event_subscriber_t led_subscriber;


/* Alternative: Manual state indication without events */
static void indicate_system_error(const char *error_msg)
{
    LOG_ERR("%s", error_msg);
    set_color_led_state(RGB_RED, true);
}

#if 0
/* Example usage in button handlers: */
static void button0_work_handler_with_led(struct k_work *work)
{
    /* ... existing code ... */
    
    if (press_duration >= BUTTON_LONG_PRESS_MS) {
        logger_state_t state = logger_get_state();
        if (state == LOGGER_STATE_IDLE) {
            logger_arm();
            set_color_led_state(RGB_GREEN, true);  /* Armed */
        } else if (state == LOGGER_STATE_ARMED) {
            logger_disarm();
            set_color_led_state(RGB_BLACK, true);   /* Back to idle */
        }
    }
}


/* Special patterns for specific conditions */
static void indicate_storage_full(void)
{
    /* Could implement a fast blink or different pattern */
    set_color_led_state(RGB_MAGENTA, true);
}

static void indicate_gnss_lock(void)
{
    /* Brief green flash when GNSS gets lock */
    set_color_led_state(RGB_GREEN, true);
    k_msleep(100);
    /* Return to current state color */
    update_led_for_state(logger_get_state());
}

static void test_version_output(const char *line, size_t len)
{
    /* Print to console for verification */
    //printk("Generated: %.*s", len, line);
    
    /* Verify checksum */
    if (!nmea_verify_checksum(line, len)) {
        printk("Checksum error!\n");
    }
}
#endif

int main(void)
{
    int ret;

    /*
     * Quiet the GNSS module VERY early - before any other initialization.
     * The SAM-M10Q continues running after CPU reset and will flood the
     * UART with NMEA data, causing buffer overruns if we wait too long.
     */
    gnss_early_quiet();

    //printk("boot\n");
    LOG_INF("Tempo-BT started");

    if (!gpio_is_ready_dt(&led)) {
		//return 0;
	}
	ret = gpio_pin_configure_dt(&led, GPIO_OUTPUT_ACTIVE);

    ret = buttons_init();
    if (ret < 0) {
        LOG_ERR("Failed to initialize buttons: %d", ret);
    }

#ifdef CONFIG_USB_TTY_OUTPUT
    /* Initialize USB early so host can enumerate during slow SD card init */
    ret = usb_tty_init();
    if (ret < 0) {
        LOG_ERR("USB TTY init failed: %d", ret);
        /* Non-critical — continue without USB TTY capability */
    }
    usb_cmd_init();
#endif

    // Initialize storage first
    ret = app_storage_init(); 
    if (ret < 0) {
        LOG_ERR("Failed to initialize storage: %d", ret);
        return ret;
    }

    // Now initialize app (which includes BLE/mcumgr)

    LOG_INF("Calling app_init()");
    ret = app_init();
    if (ret < 0) {
        LOG_ERR("Failed to initialize app: %d", ret);
    }

    /* Initialize event bus */
    ret = event_bus_init();
    if (ret < 0) {
        LOG_ERR("Failed to initialize event bus: %d", ret);
    }
    
#if 0
    /* Subscribe to test events */
    ret = event_bus_subscribe(&test_subscriber, 
                             test_event_handler,
                             (1U << EVT_TEST_DUMMY) | (1U << EVT_MODE_CHANGE),
                             NULL);
    if (ret < 0) {
        LOG_ERR("Failed to subscribe to events: %d", ret);
    }
    
    /* Publish a test event */
    LOG_INF("Publishing test event");
    event_bus_publish_simple(EVT_TEST_DUMMY);
    
    /* Give event thread time to process */
    k_msleep(10);
    
    /* Test settings */
    LOG_INF("About to test settings...");
    app_settings_test();
    LOG_INF("Settings test done");
#endif
    
    /* Initialize timebase */
    LOG_INF("About to init timebase...");
    ret = timebase_init();
    if (ret < 0) {
        LOG_ERR("Failed to initialize timebase: %d", ret);
    }
    LOG_INF("Timebase init done");

    ret = aggregator_init();
    if (ret < 0) {
        LOG_ERR("Failed to initialize aggregator: %d", ret);
    }
    LOG_INF("Aggregator init done");    

    //aggregator_register_output_callback(test_version_output);
    //aggregator_write_version();

    //logger_register_baro_callback(logger_baro_handler);
    
    /* Register both callbacks with barometer service */
    extern void logger_baro_handler(const baro_sample_t *sample);
    
    /* Register the logger's barometer callback for takeoff detection */
    ret = baro_register_callback(logger_baro_handler);
    if (ret < 0) {
        LOG_ERR("Failed to register logger baro callback: %d", ret);
        /* Non-critical - continue without automatic takeoff detection */
    } else {
        LOG_INF("Logger barometer callback registered for takeoff detection");
    }
    
    #if 0
    /* Test monotonic timer */
    LOG_INF("Testing monotonic timer...");
    uint64_t t1 = time_now_us();
    k_msleep(10);
    uint64_t t2 = time_now_us();
    LOG_INF("10ms sleep measured as %llu us", t2 - t1);
    
    /* Test UTC correlation (should fail initially) */
    uint64_t utc_ms;
    if (timebase_mono_to_utc(time_now_us(), &utc_ms)) {
        LOG_INF("UTC time available: %llu ms", utc_ms);
    } else {
        LOG_INF("UTC correlation not available yet: %s", 
                timebase_utc_string_placeholder());
    }
    
    LOG_INF("About to check QSPI flash...");
    
    /* Check if QSPI flash device is ready */
    const struct device *flash_dev = DEVICE_DT_GET(DT_NODELABEL(mx25r64));
    if (!device_is_ready(flash_dev)) {
        LOG_ERR("QSPI flash device not ready");
    } else {
        LOG_INF("QSPI flash device is ready");
        
        /* Get flash parameters */
        const struct flash_parameters *flash_params = flash_get_parameters(flash_dev);
        LOG_INF("Flash write block size: %d", flash_params->write_block_size);
        
        /* Get flash size */
        uint64_t flash_size;
        int res = flash_get_size(flash_dev, &flash_size);
        if (res == 0) {
            LOG_INF("Flash size: %llu bytes", flash_size);
        }
        
        /* Try to get page info */
        struct flash_pages_info info;
        ret = flash_get_page_info_by_offs(flash_dev, 0, &info);
        if (ret == 0) {
            LOG_INF("Flash page size: %d, start offset: 0x%x", 
                    info.size, (unsigned int)info.start_offset);
        }
    }
    #endif

    /* Initialize GNSS */
    LOG_INF("Initializing GNSS...");
    ret = gnss_init();
    if (ret < 0) {
        LOG_ERR("Failed to initialize GNSS: %d", ret);
        /* GNSS failure is not critical - continue without it */
    } else {
        LOG_INF("GNSS initialized successfully");

#ifdef CONFIG_GNSS_TEST_MODE
        /* Run UBX communication tests before configuring */
        ret = gnss_test_ubx_communication();
        if (ret < 0) {
            LOG_ERR("GNSS UBX communication test FAILED");
        } else {
            LOG_INF("GNSS UBX communication test PASSED");
        }
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

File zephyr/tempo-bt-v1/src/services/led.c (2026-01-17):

/*
 * SPDX-License-Identifier: Apache-2.0
 *
 * Tempo-BT V1 - RGB LED Service Implementation
 *
 * Controls an RGB LED using PWM, providing a 50ms blink once per second.
 * Also controls led1 (red GPIO LED) to indicate GPS lock status.
 */

#include <zephyr/kernel.h>
#include <zephyr/logging/log.h>
#include <zephyr/drivers/pwm.h>
#include <zephyr/drivers/gpio.h>
#include <zephyr/device.h>

#include "services/led.h"
#include "services/gnss.h"

LOG_MODULE_REGISTER(led_service, LOG_LEVEL_INF);

/* GPIO LED for GPS status indicator (led1 = red LED) */
#define GPS_LED_NODE DT_ALIAS(led1)
#if DT_NODE_EXISTS(GPS_LED_NODE)
static const struct gpio_dt_spec gps_led = GPIO_DT_SPEC_GET(GPS_LED_NODE, gpios);
static bool gps_led_available = false;
#endif

/* PWM configuration */
#define LED_PWM_NODE DT_NODELABEL(pwm0)
#define LED_PWM_CHANNEL_R 0  /* Red on channel 0 */
#define LED_PWM_CHANNEL_G 1  /* Green on channel 1 */
#define LED_PWM_CHANNEL_B 2  /* Blue on channel 2 */

/* Timing configuration */
#define BLINK_PERIOD_MS    2000  /* 2 second period */ 
#define BLINK_ON_TIME_MS   50    /* 50ms on time */
#define PWM_PERIOD_NS      1000000  /* 1ms PWM period for smooth dimming */ 

/* LED state */
static struct {
    const struct device *pwm_dev;
    rgb_color_t current_color;
    bool enabled;
    struct k_timer blink_timer;
    bool led_on;
    struct k_mutex mutex;
    rgb_color_t override_color;
    bool override_enabled;
    rgb_color_t app_color;      
    bool app_enabled;           
} led_state = {
    .pwm_dev = NULL,
    .current_color = RGB_BLACK,
    .enabled = false,
    .led_on = false,
    .override_color = RGB_BLACK,
    .override_enabled = false,
    .app_color = RGB_BLACK,
    .app_enabled = false
};

/* Forward declaration */
static void blink_timer_handler(struct k_timer *timer);
static void led_off(void);

/* Timer work item for turning LED off */
static struct k_work_delayable led_off_work;

/* Work handler to turn LED off */
static void led_off_work_handler(struct k_work *work)
{
    ARG_UNUSED(work);
    led_off();
}

/**
 * @brief Set PWM duty cycle for a color channel
 */
static int set_pwm_channel(uint32_t channel, uint8_t brightness)
{
    uint32_t pulse_ns;
    int ret;
    
    // For common anode LEDs, we need to invert the brightness
    // 0 brightness = full PWM duty (LED OFF)
    // 255 brightness = 0 PWM duty (LED ON)
    uint8_t inverted_brightness = 255 - brightness;
    
    // Still use the bit-shifted value if you want dimmer LEDs
    // For full brightness, remove the >> 3
    inverted_brightness = inverted_brightness >> 3;  // Scale to 0-31 range
    
    pulse_ns = ((uint32_t)inverted_brightness * PWM_PERIOD_NS) / 31;
    
    LOG_DBG("Setting PWM ch%d: brightness=%d (inverted=%d), pulse=%d ns", 
            channel, brightness, inverted_brightness, pulse_ns);
    
    ret = pwm_set(led_state.pwm_dev, channel, PWM_PERIOD_NS, pulse_ns, 0);
    if (ret < 0) {
        LOG_ERR("Failed to set PWM channel %d: %d", channel, ret);
    }
    
    return ret;
}

/**
 * @brief Turn LED on with current color
 */
static void led_on(void)
{
    k_mutex_lock(&led_state.mutex, K_FOREVER);

    if (led_state.enabled) {
        set_pwm_channel(LED_PWM_CHANNEL_R, led_state.current_color.r >> 3);
        set_pwm_channel(LED_PWM_CHANNEL_G, led_state.current_color.g >> 3);
        set_pwm_channel(LED_PWM_CHANNEL_B, led_state.current_color.b >> 3);
        led_state.led_on = true;

        /* Turn on GPS status LED (red) if no GPS fix */
#if DT_NODE_EXISTS(GPS_LED_NODE)
        if (gps_led_available && !gnss_has_fix()) {
            gpio_pin_set_dt(&gps_led, 0);  /* Active low: 0 = LED on */
        }
#endif
    }

    k_mutex_unlock(&led_state.mutex);
}

/**
 * @brief Turn LED off
 */
static void led_off(void)
{
    k_mutex_lock(&led_state.mutex, K_FOREVER);

    set_pwm_channel(LED_PWM_CHANNEL_R, 0);
    set_pwm_channel(LED_PWM_CHANNEL_G, 0);
    set_pwm_channel(LED_PWM_CHANNEL_B, 0);
    led_state.led_on = false;

    /* Always turn off GPS status LED when RGB LED turns off */
#if DT_NODE_EXISTS(GPS_LED_NODE)
    if (gps_led_available) {
        gpio_pin_set_dt(&gps_led, 1);  /* Active low: 1 = LED off */
    }
#endif

    k_mutex_unlock(&led_state.mutex);
}

/**
 * @brief Blink timer handler
 */
static void blink_timer_handler(struct k_timer *timer)
{
    ARG_UNUSED(timer);
    
    /* Only turn on if currently off */
    if (!led_state.led_on) {
        /* Turn LED on */
        led_on();
        
        /* Schedule LED off after 50ms */
        k_work_reschedule(&led_off_work, K_MSEC(BLINK_ON_TIME_MS));
    }
}

/**
 * @brief Initialize the LED service
 */
int led_service_init(void)
{
    /* Get PWM device */
    led_state.pwm_dev = DEVICE_DT_GET(LED_PWM_NODE);
    if (!device_is_ready(led_state.pwm_dev)) {
        LOG_ERR("PWM device not ready");
        return -ENODEV;
    }

    /* Initialize GPS status LED (led1 - red LED) */
#if DT_NODE_EXISTS(GPS_LED_NODE)
    if (gpio_is_ready_dt(&gps_led)) {
        int gps_led_ret = gpio_pin_configure_dt(&gps_led, GPIO_OUTPUT_INACTIVE);
        if (gps_led_ret == 0) {
            gps_led_available = true;
            LOG_INF("GPS status LED (led1) initialized");
        } else {
            LOG_WRN("Failed to configure GPS LED: %d", gps_led_ret);
        }
    } else {
        LOG_WRN("GPS LED device not ready");
    }
#endif

    /* Initialize mutex */
    k_mutex_init(&led_state.mutex);

    /* Initialize timer */
    k_timer_init(&led_state.blink_timer, blink_timer_handler, NULL);

    /* Initialize work item */
    k_work_init_delayable(&led_off_work, led_off_work_handler);

    /* Turn off all channels initially */
    led_off();

    LOG_INF("LED service initialized");

    return 0;
}

/**
 * @brief Set RGB LED color and state
 */
int set_color_led_state(rgb_color_t color, bool state)
{
    k_mutex_lock(&led_state.mutex, K_FOREVER);
    
    /* Store application state */
    led_state.app_color = color;
    led_state.app_enabled = state;
    
    /* Only update actual LED if override is not active */
    if (!led_state.override_enabled) {
        led_state.current_color = color;
        led_state.enabled = state;
        
        if (state) {
            /* Start blinking timer */
            k_timer_start(&led_state.blink_timer, 
                        K_NO_WAIT,
                        K_MSEC(BLINK_PERIOD_MS));
        } else {
            /* Stop timer and turn off LED */
            k_timer_stop(&led_state.blink_timer);
            k_work_cancel_delayable(&led_off_work);
            led_off();
        }
    }
    
    k_mutex_unlock(&led_state.mutex);
    
    return 0;
}
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

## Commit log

2025-11-14 Pared to just Tempo-BT board
    [10103594-0001LF.step, 10103594.stp, 20021521-00010XXLFc.stp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]
2025-12-20 Update Keystone Battery holder
    [tempo-bt.kicad_sch]
2026-01-11 Updated enclosure
    [Enclosure-Bottom.step, Enclosure-Top.step, Pushbuttons.step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]
2026-01-13 Update README with assembly parts list
    Added a parts list for enclosure assembly.
2026-01-17 Add logging state executive function. Fixed several issues in the u-blox GNSS driver. Updated state RGB LED colors. Logging works.
    [gnss.h, gnss_m10q.c, led.c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]
2026-01-17 Update LED documentation.
2026-01-17 Orientation testing - fixes and simplified.
    [imu_icm42688.c, main.c, mcumgr_custom.c]
2026-01-18 Run GNSS UART at 115200bps. Refine scale ranges for IMU gyro and accelerometer down to more reasonable values.
2026-01-18 LED service wasn't properly picking up on logging state changes. Disable one obsolete logging state transition check.
2026-01-19 Create NCS V3.2.1 patch for IMU and add custom device driver for Memsic MMC5983MA Magnetometer
2026-01-19 Fix situations where LED color was sometimes not in-sync the current logging state.
    [main.c]
2026-01-28 Increase work queue stack size and remove some IMU debugging statements
2026-01-30 Use 1Hz SAM-M10Q time base signal to synchronize multiple Tempo-BT devices for simultaneous testing. In this phase, we blink the Green LED to get an indication of how synchronized the devices end up.
2026-01-30 Add image of device
2026-01-31 Bring documentation in line with the current implementation.,
2026-01-31 Add filtered accelerometer reading to criteria for detecting the start of a jump.
2026-02-01 Fixes and improved logging for mcumgr date-time and test commands.
    [gnss_m10q.c, mcumgr_custom.c]
2026-02-01 Increase UART buffer size. Disable GSA/RMC messages when GPS logging at greater than 1HZ.
2026-02-01 Successful on-ground remotely controlled logging test. Reduced GNSS UART RX timeout.
2026-02-05 Output PIMU records; reduce IMU report rate to 20Hz
2026-02-16 Add USB logging for interactive IMU tests. Marked as version 1.1.0
2026-02-17 Add desktop interactive IMU/Fusion algorithm testing tool
2026-02-18 Fix issue in visualization.
    [visualizer.py]
2026-02-25 Disable BLE while logging. https://github.com/rrainey/tempo-bt/issues/2 BLE name set function wasn't working.
    [mcumgr_custom.c]
2026-02-27 Add revised "high brim" enclosure
    [Enclosure-Bottom.step, Enclosure-Bottom.stl, Enclosure-Top.step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]
2026-03-04 Add Magnetometer calibration and runtime integration. MCUMGR interactions remain to be tested.
2026-03-05 Mag compass calibration and integration.
2026-03-07 Add magnetic sensor axes and polarity
2026-04-03 Logger $PST sentences now inject an appropriate reason into the log when logging is started. A stack overflow issue when manually starting logging was fixed.
    [main.c, mcumgr_custom.c, timebase.c]
2026-07-07 V1.5.0 release: Fix issue in the SESSION_LIST mcumgr command to return both the <date> and <random-id> directory elements as a session name.
    [mcumgr_custom.c]
2026-07-12 Issue #9 comment — root cause of the stale app_version.h (mtime-gated rule + stale tracked copy in the source tree), the always-run CMake target, script robustness fixes, and how it was verified. Iss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
    [mcumgr_custom.c]
2026-07-17 Fix log-stream corruption from unsynchronized file_writer ring buffer
    Concurrent producers (system workqueue IMU/env output, GNSS thread NMEA
    passthrough, main-thread state changes) called ring_buf_put() on a ring
    buffer that is only single-producer safe. Overlapping space claims
    truncated sentences, fused adjacent sentences, and occasionally leaked
    one-lap-stale ring contents into flight.txt — confirmed against 51
    corrupt lines across 23 of 47 harvested logs, all matching these
    signatures. The partial-put path compounded it by enqueuing line
    prefixes and retrying the tail after a k_yield() that could never run
    the (lower-priority) writer thread.
    file_writer_write() now serializes produce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
